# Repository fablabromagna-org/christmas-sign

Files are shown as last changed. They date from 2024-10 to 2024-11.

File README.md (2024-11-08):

# christmas-sign
Tre pomeriggi di open lab per realizzare insieme delle decorazioni a LED utilizzando CAD 2D-3D, Stampa 3D a colori, coding Arduino e Circuit Python.

# Circuito di controllo dei led
Il primo disegno KiCad prodotto è nella cartella ATtiny3.

La scelta di utilizzare un ATtiny è legata alla semplicità ed economicità di questa serie di microcontrollori.

L'idea era quella di creare un circuito che:
- potesse essere usato su una breadboard per i primi esperimenti
- fosse alimentabile con un cavo USB-C
- avesse a bordo un regolatore per 3.3v
- portasse fuori tutti i pin del'ATTiny
- avesse a bordo i driver di potenza per pilotare i led direttamente
- potesse essere programmato con un connettore UPDI standard a 6 pin (di cui solo 3 utilizzati)

Molti componenti sono SMD basic che non richiedono quindi una spesa aggiuntiva per il cambio reel sul Pick and place di JLCPCB.

Gli unici componenti extended sono:
- il connettore USB-C
- il regolatore di tensione 3.3v
- la CPU

La prima produzione di 10 schede per un totale di 434 componenti montati in SMD è costata 37 euro comprese VAT e shipping. (avevo un buono sconto di 8,26 euro)

A queste spese bisogna aggiungere le 10 CPU comprate su Mouser a 9,39 che andranno saldate a mano.

JLCPCB infatti non ha a catalogo queste CPU (ATtiny1624)

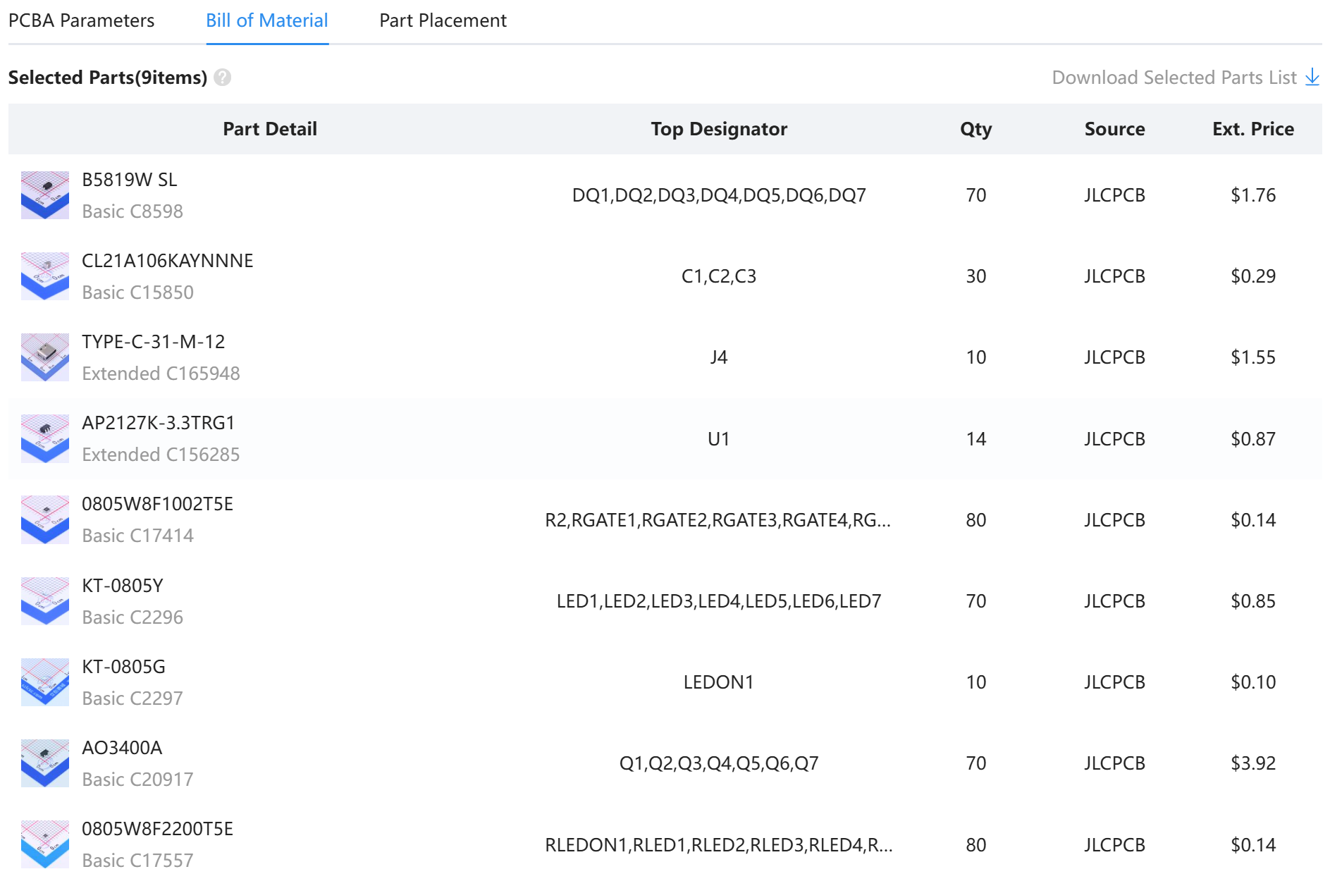
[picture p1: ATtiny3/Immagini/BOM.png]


Fronte
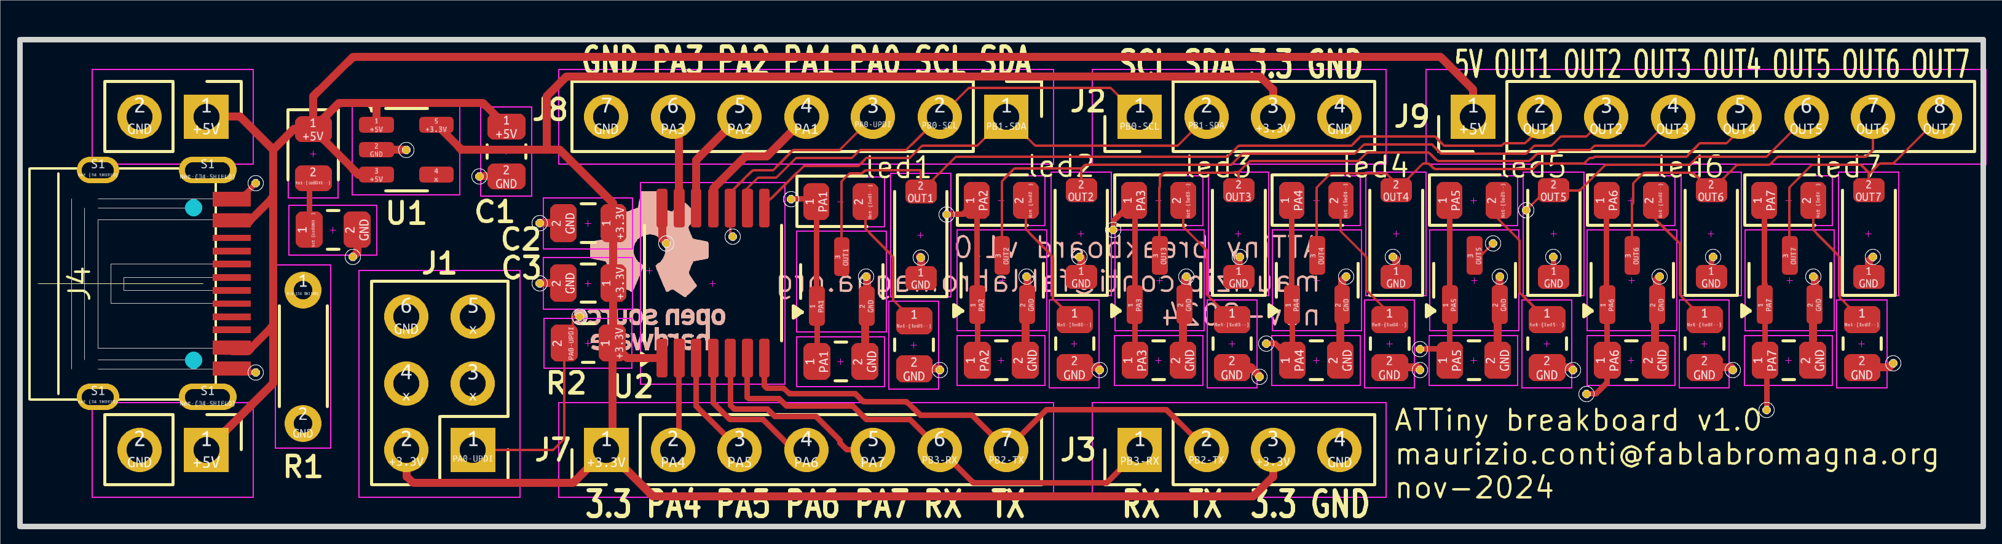
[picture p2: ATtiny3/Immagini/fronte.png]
Fronte


Retro
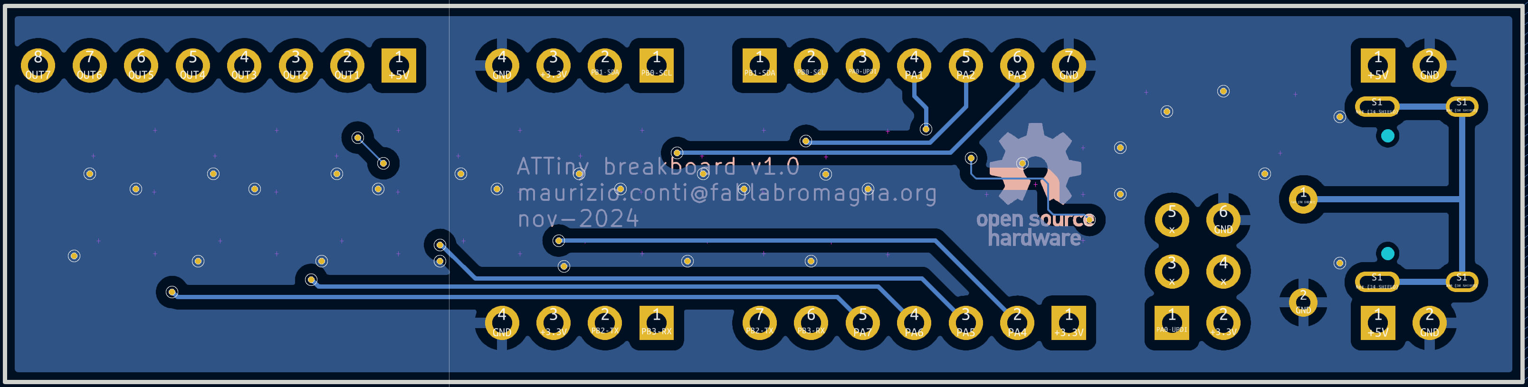
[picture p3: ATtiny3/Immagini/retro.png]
Retro


Schema
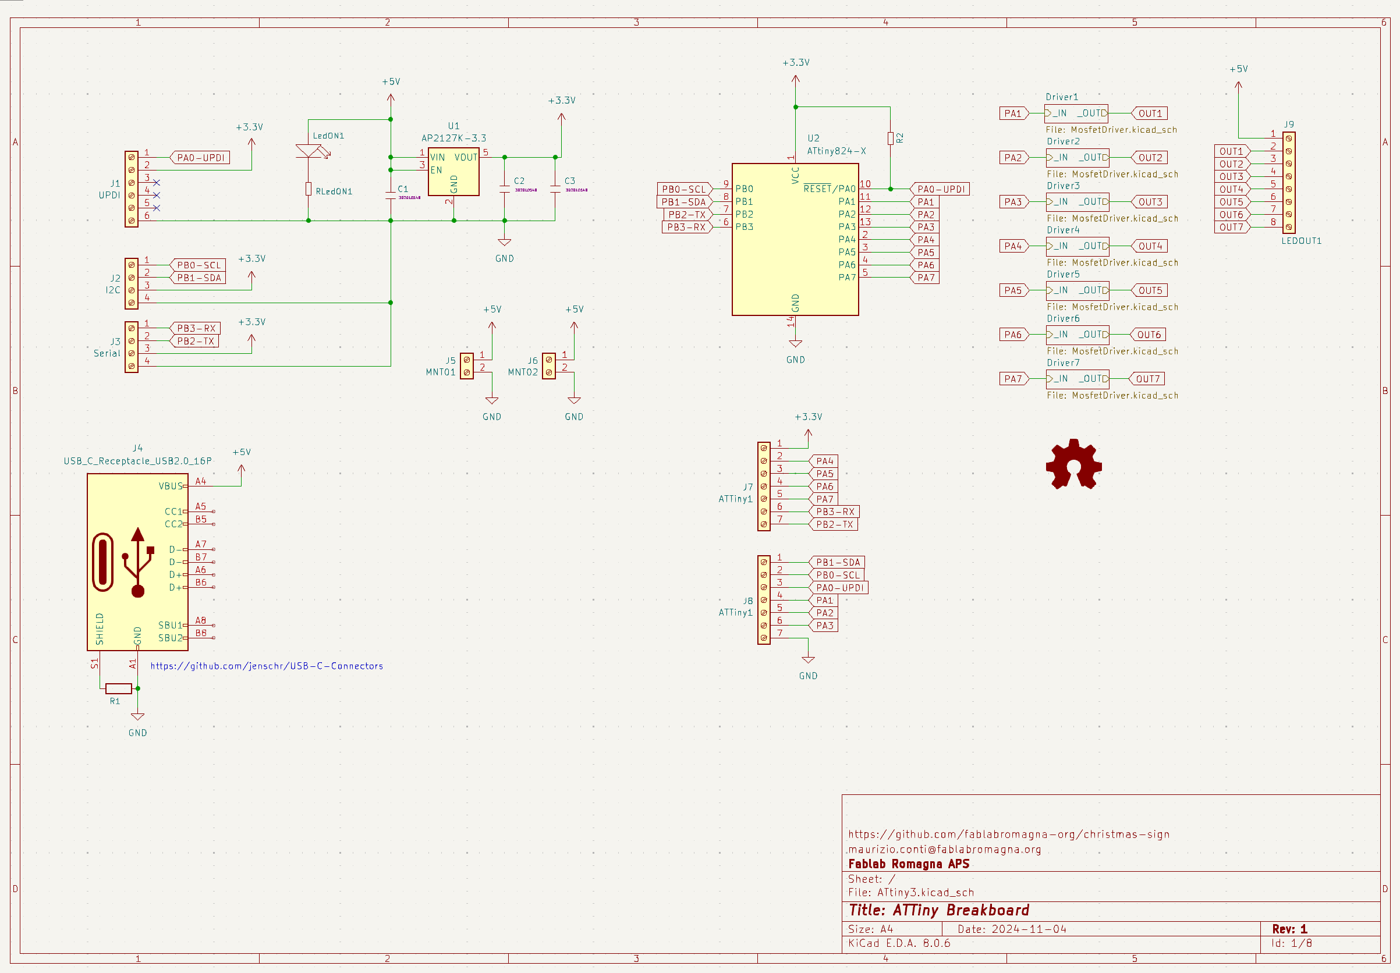
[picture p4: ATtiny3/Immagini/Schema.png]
Schema


Vista 3D
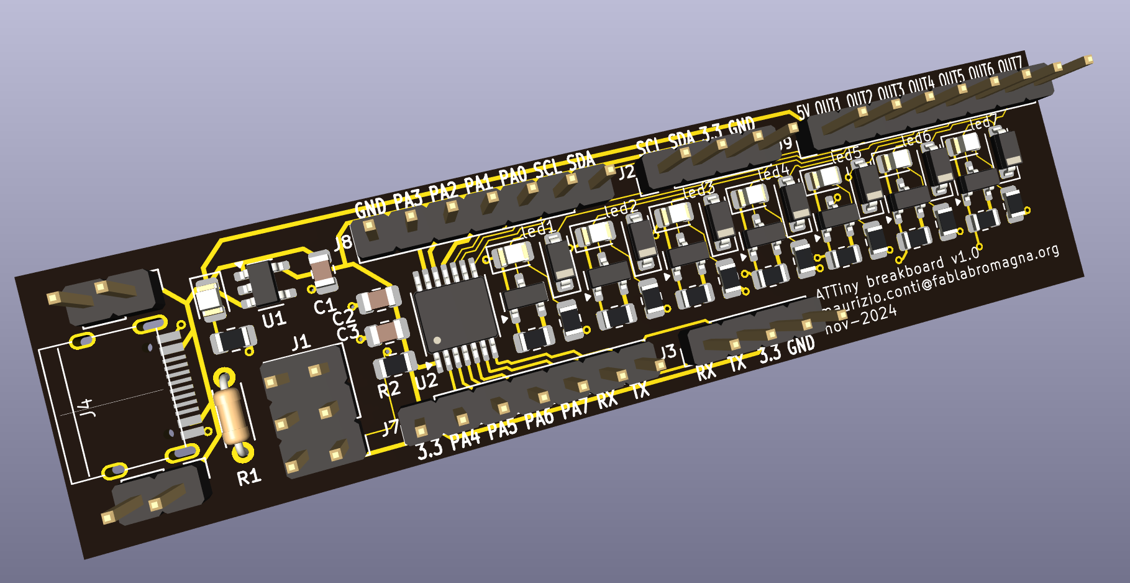
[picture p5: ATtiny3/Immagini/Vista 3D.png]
Vista 3D


Pdf dello schema **[PDF](ATtiny3/Immagini/Schema.pdf)**.

Così lo volevano loro...
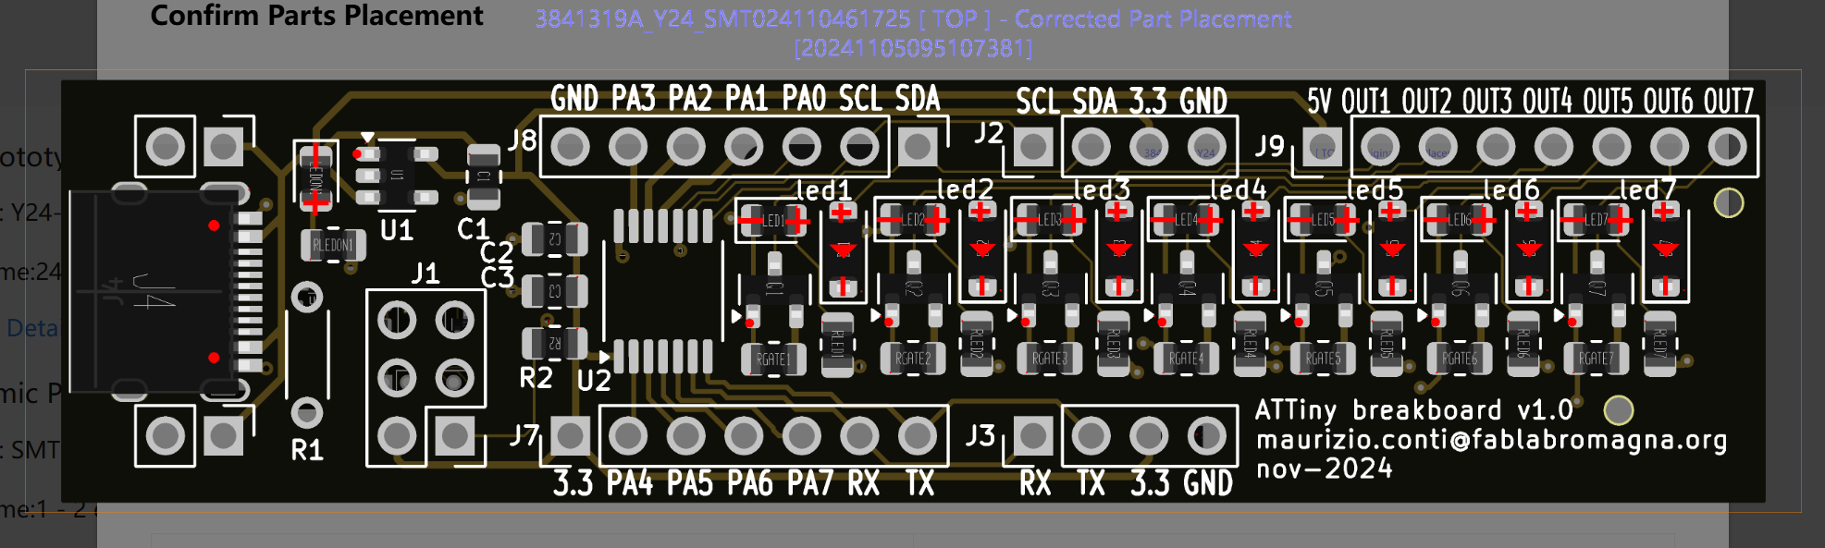
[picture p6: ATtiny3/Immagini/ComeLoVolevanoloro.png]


Così lo volevo io...
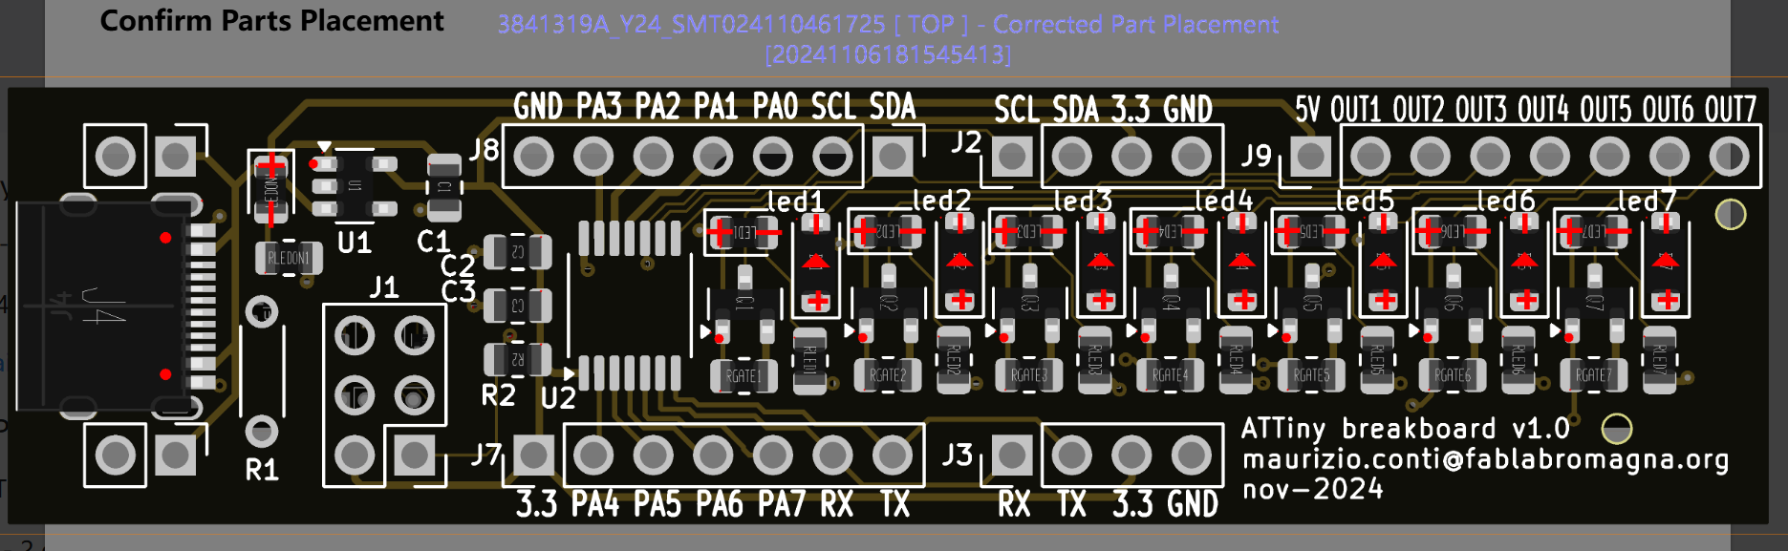
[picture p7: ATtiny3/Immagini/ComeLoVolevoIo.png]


Ci siamo messi d'accordo.
I diodi erano giusti ma a loro non piacevano.

Quando arriveranno i circuiti montati sapremo chi aveva ragione.

Nel frattempo però, un circuito confermato domenica 3 novembre 2024, va in produzione l'8 novembre, con 5 giorni di ritardo.

Loro chiedono scusa ma la prossima volta lo faccio con PCBWay e vediamo se il maggior costo è giustificato.

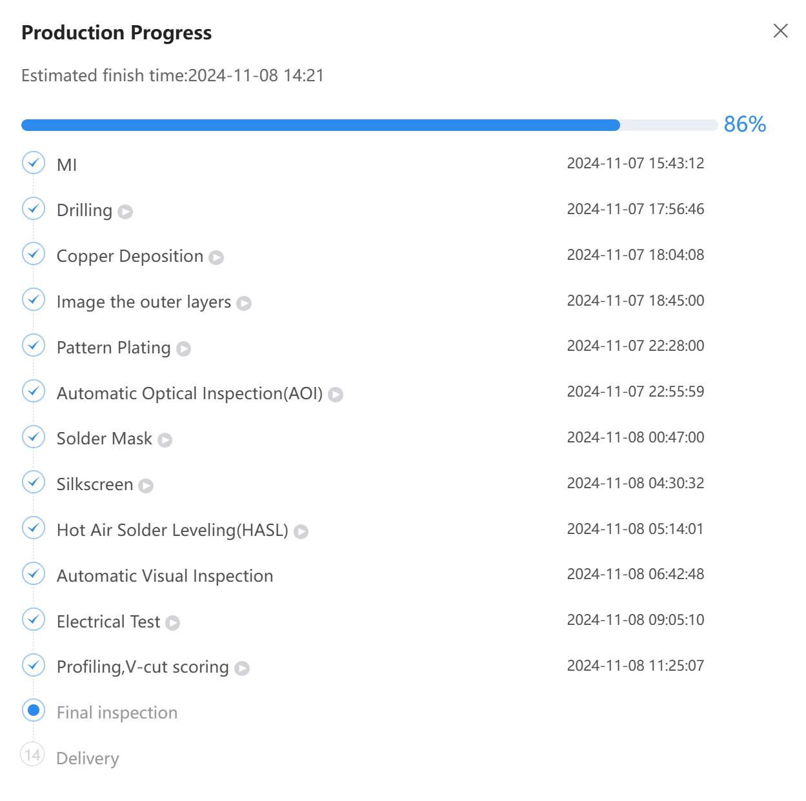
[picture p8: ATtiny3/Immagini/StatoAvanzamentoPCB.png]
Ci siamo


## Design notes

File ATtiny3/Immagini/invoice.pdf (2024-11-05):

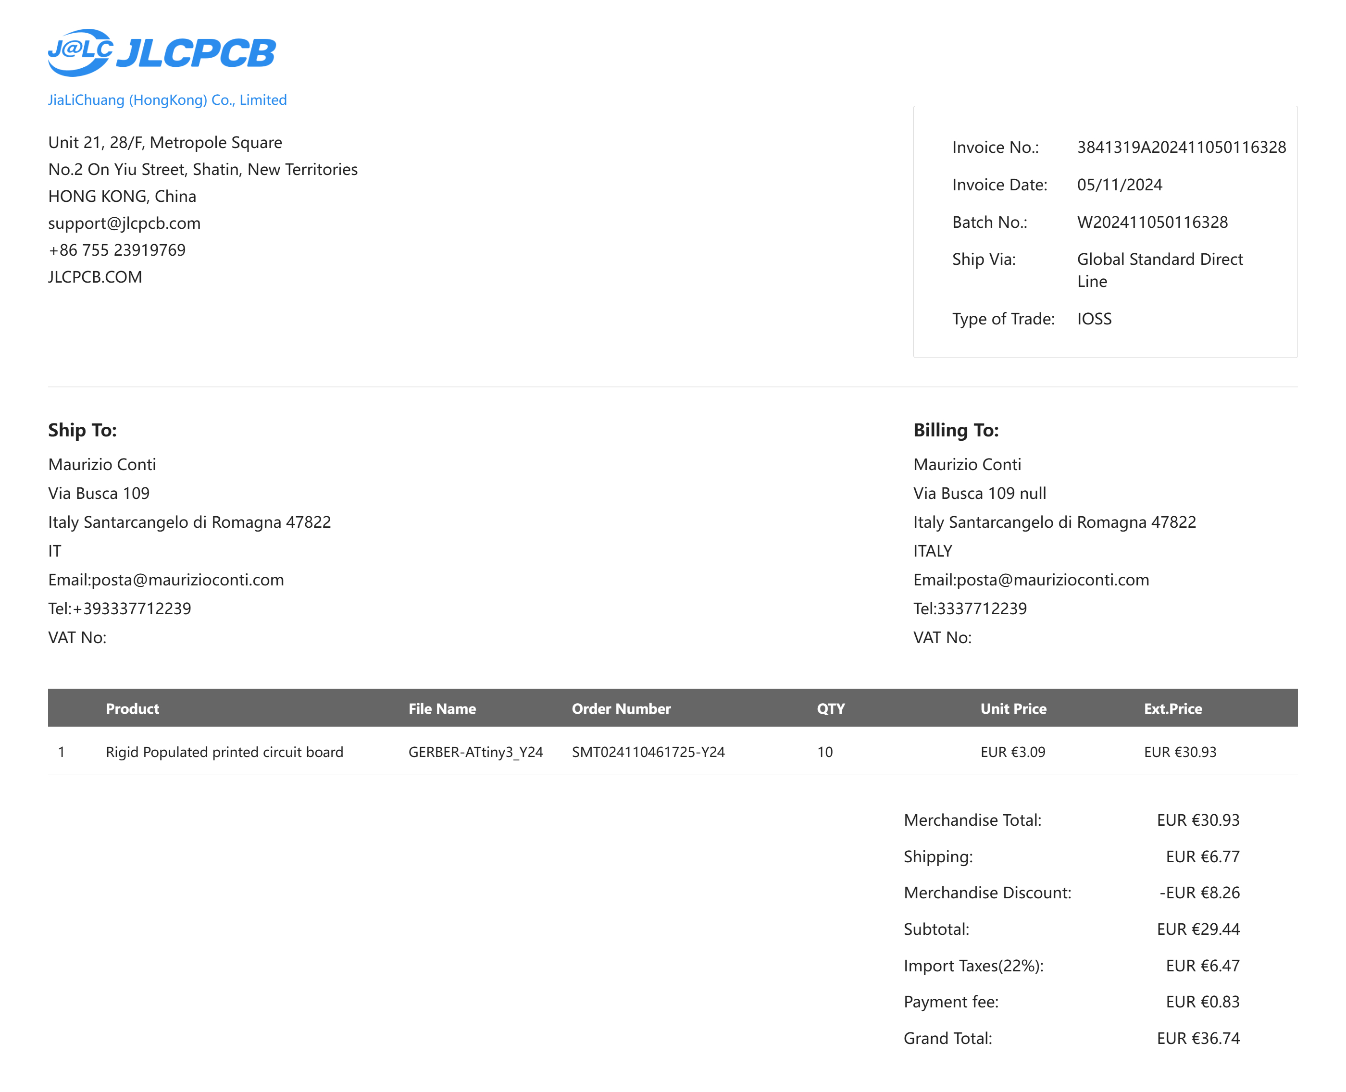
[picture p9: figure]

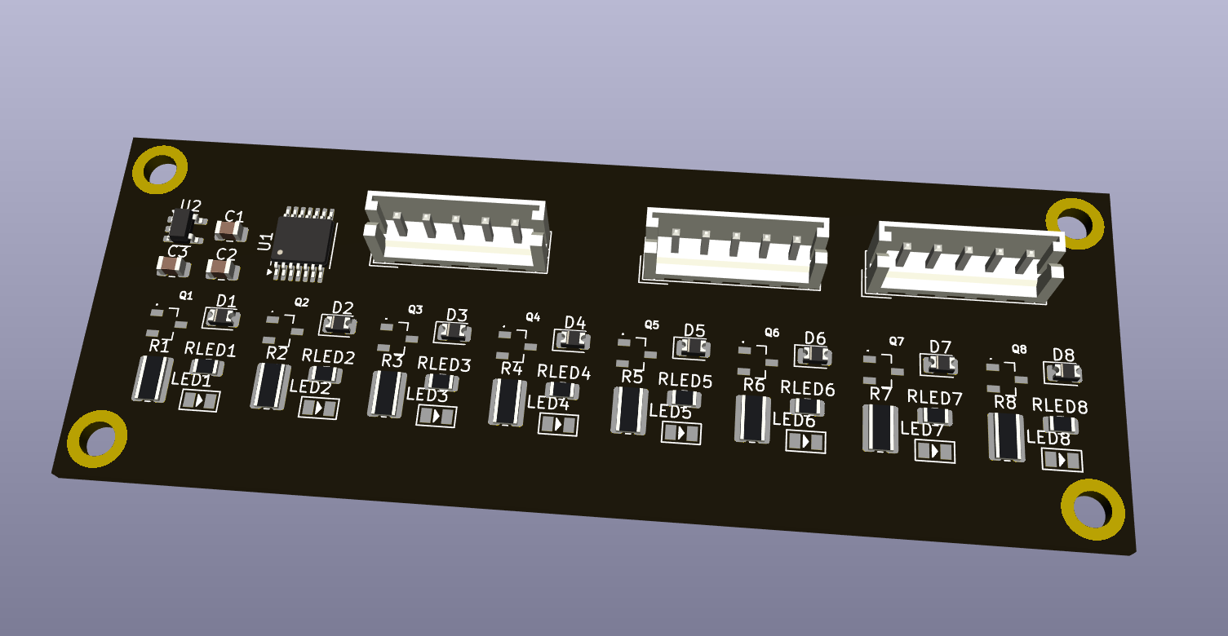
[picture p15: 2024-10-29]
ATtiny3/Immagini/primo layout.png

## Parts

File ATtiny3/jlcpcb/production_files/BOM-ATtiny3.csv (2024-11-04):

Comment | Designator | Footprint | LCSC
AP2127K-3.3 | U1 | SOT-23-5 | C156285
CERAMIC-10UF-10V-10%-X7R_0805_ | C1,C2,C3 | C_0805_2012Metric | C15850
USB_C_Receptacle_USB2.0_16P | J4 | TYPE-C-31-M-12 | C165948
10K | R2,rgate1,rgate2,rgate3,rgate4,rgate5,rgate6,rgate7 | R_0805_2012Metric | C17414
SMD-RES-220R-5%-1_8W_0805_ | RLedON1,rled1,rled2,rled3,rled4,rled5,rled6,rled7 | R_0805_2012Metric | C17557
SMD-MOSFET-N-CH | q1,q2,q3,q4,q5,q6,q7 | SOT-23 | C20917
SMD-LED-CLEAR-0805 | led1,led2,led3,led4,led5,led6,led7 | LED_0805_2012Metric | C2296
SMD-LED-CLEAR-RED_0805_ | LedON1 | LED_0805_2012Metric | C2297
SMD-DIODE-SCHOTTKY-20V-1A_SOD-123_ | dq1,dq2,dq3,dq4,dq5,dq6,dq7 | D_SOD-123 | C8598
Logo_Open_Hardware_Small | L1 | OSHW-Logo_5.7x6mm_SilkScreen

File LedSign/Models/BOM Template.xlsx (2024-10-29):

Designator | Manufacturer Part Number or Seeed SKU | Qty | Link
C1,C2,C3,C4,C5 | RHA0J471MCN1GS | 5 | https://www.digikey.com.cn/product-detail/zh/nichicon/RHA0J471MCN1GS/493-3771-1-ND/2209480
A1,A4 | RH0111-30002 | 2 | https://statics3.seeedstudio.com/images/opl/datasheet/318020010.pdf
D1 | CYBLE-014008-00 | 1 | https://www.digikey.com.cn/product-detail/zh/cypress-semiconductor-corp/CYBLE-014008-00/428-3600-1-ND/6052585

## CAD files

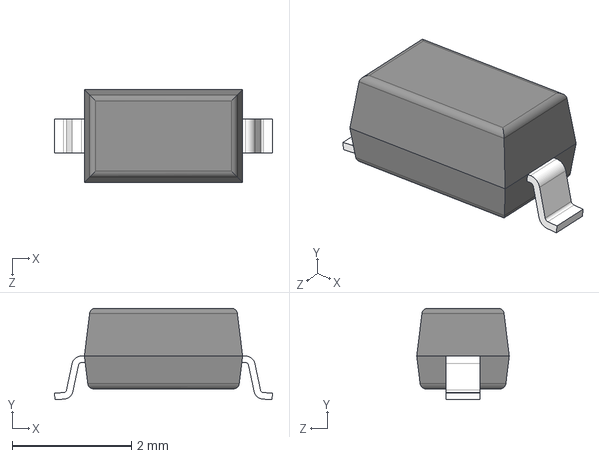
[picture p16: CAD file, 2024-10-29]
LedSign/Models/B5819W-TP.step
3.65 x 1.53 x 1.55 mm

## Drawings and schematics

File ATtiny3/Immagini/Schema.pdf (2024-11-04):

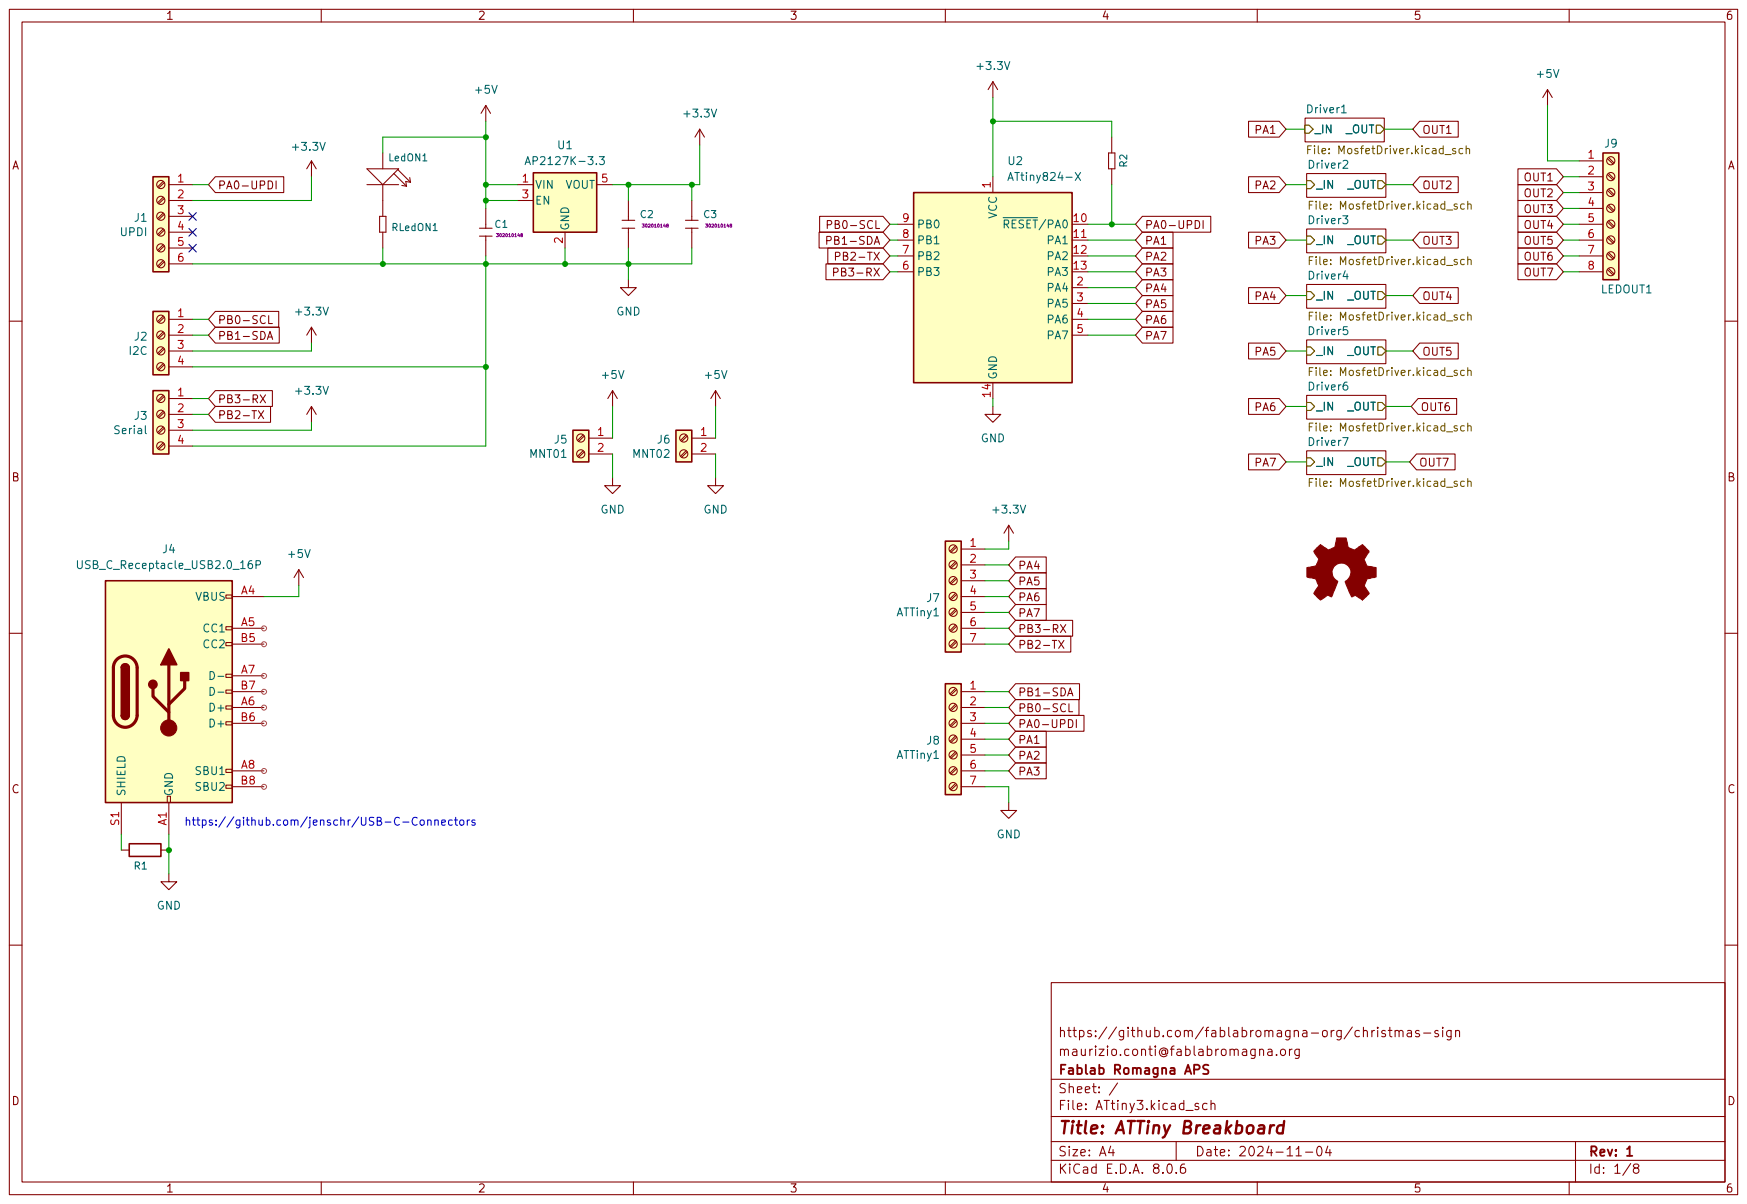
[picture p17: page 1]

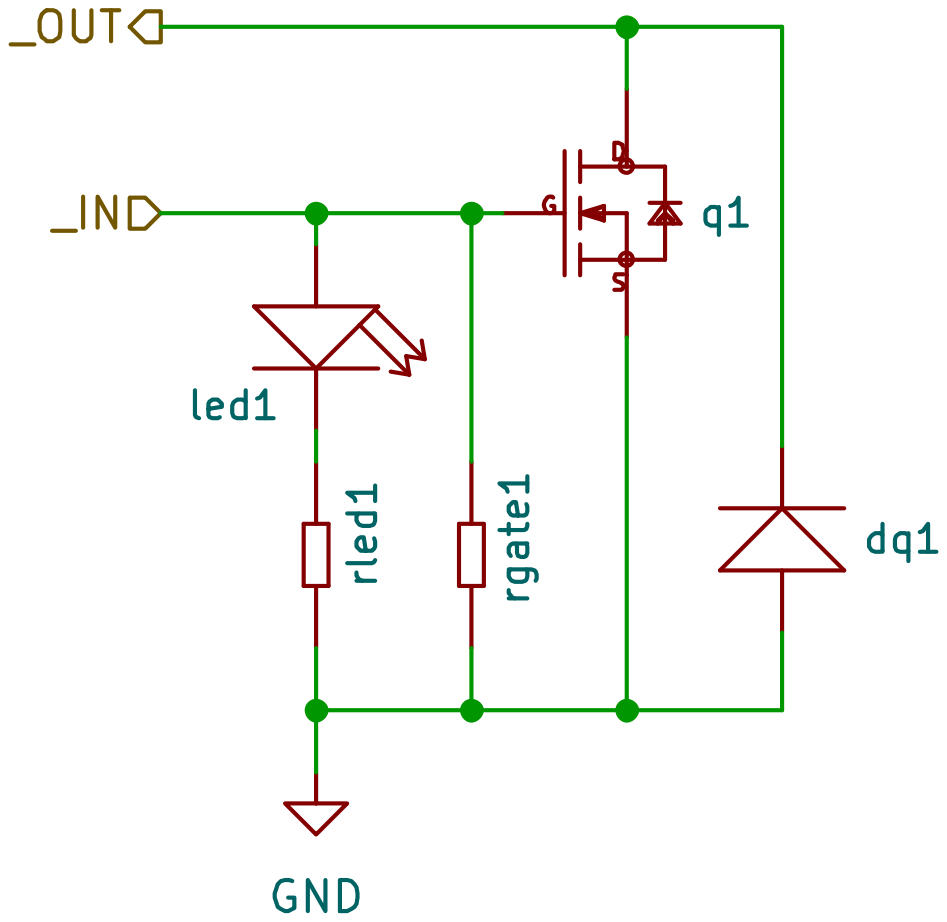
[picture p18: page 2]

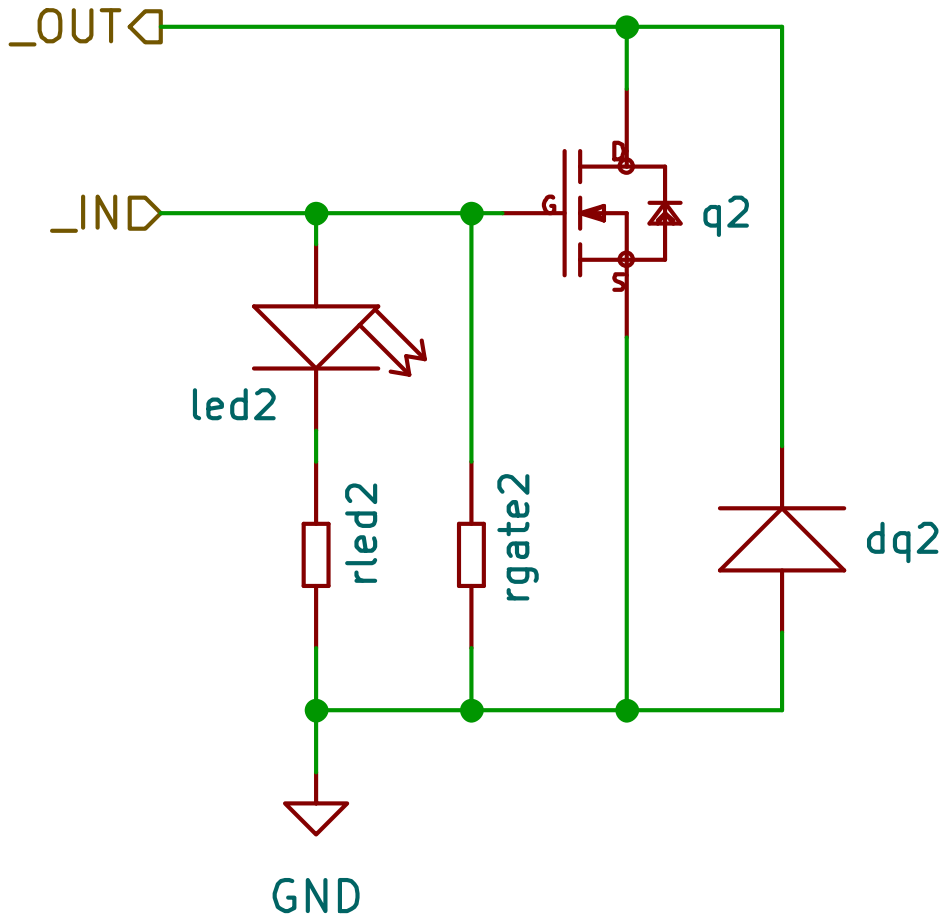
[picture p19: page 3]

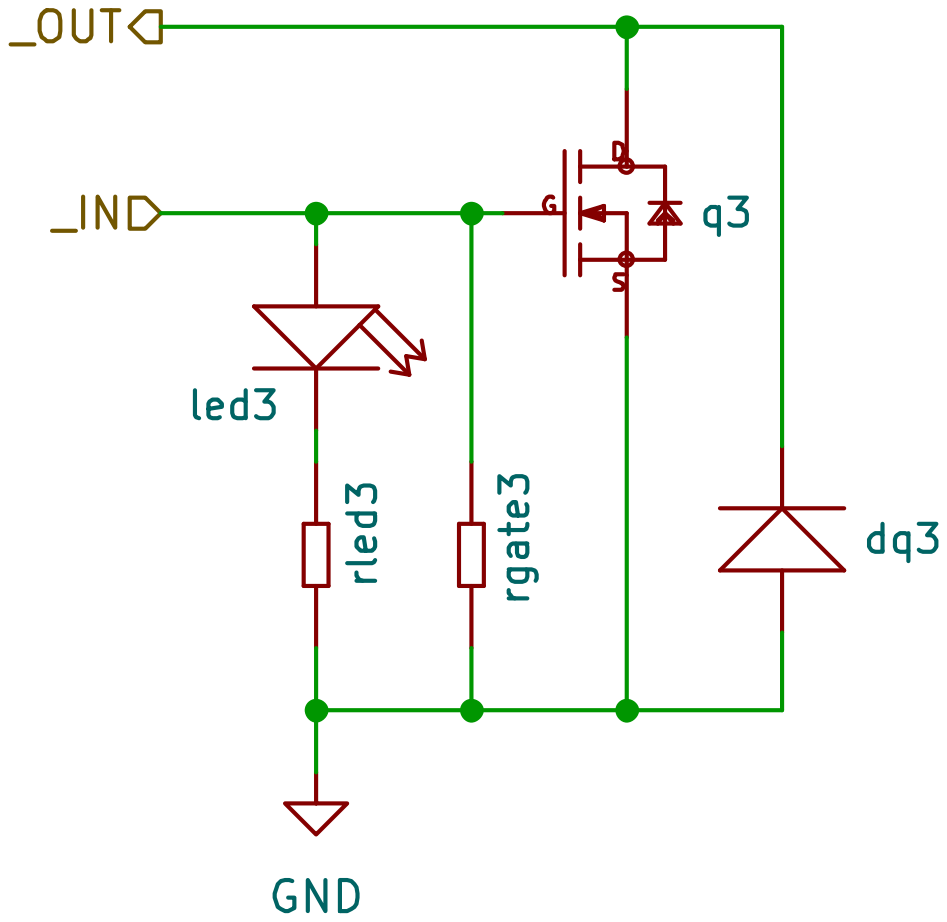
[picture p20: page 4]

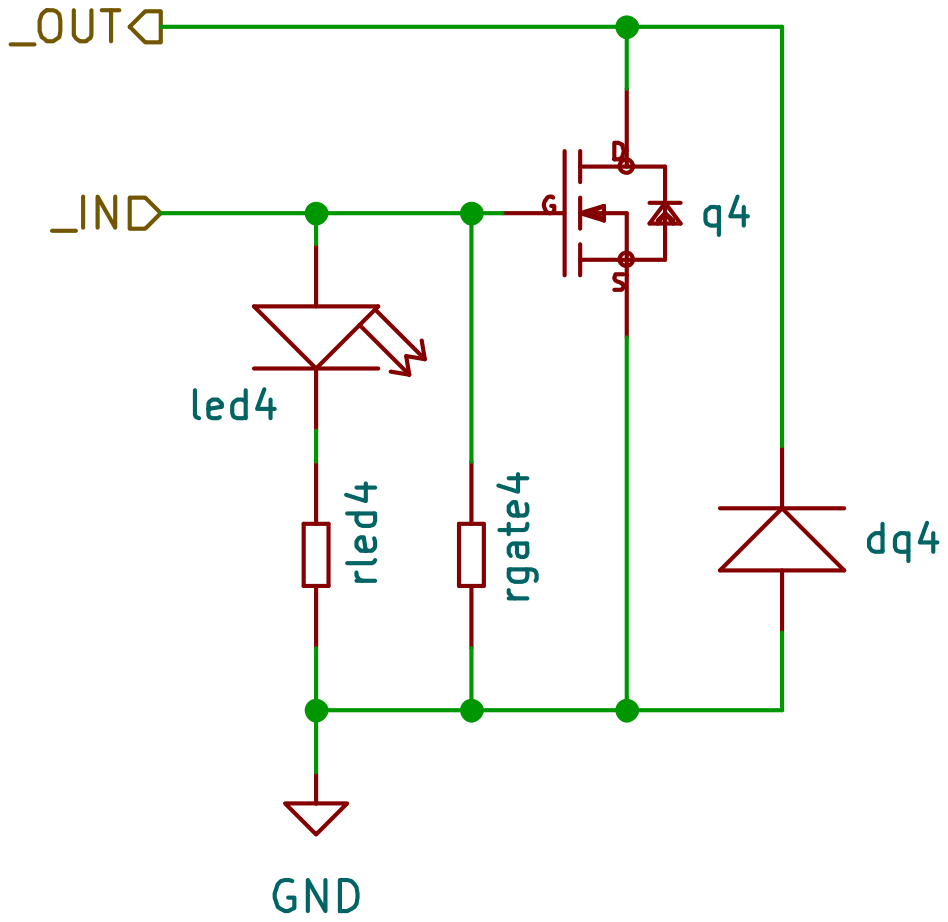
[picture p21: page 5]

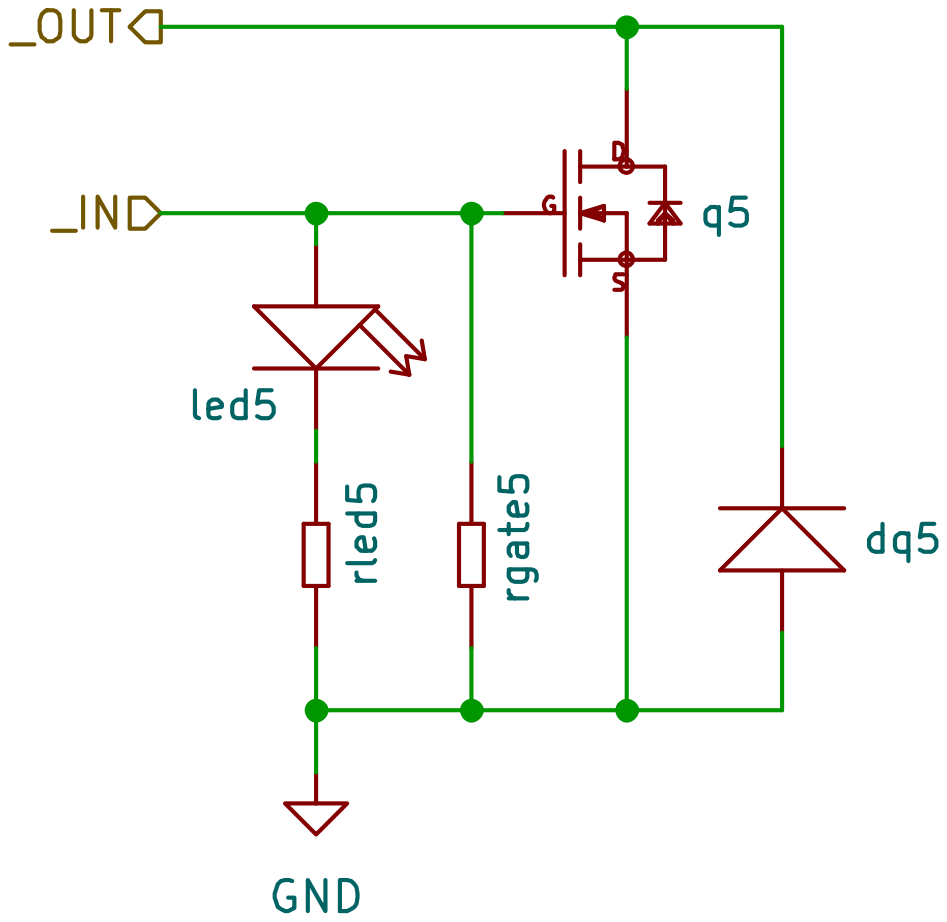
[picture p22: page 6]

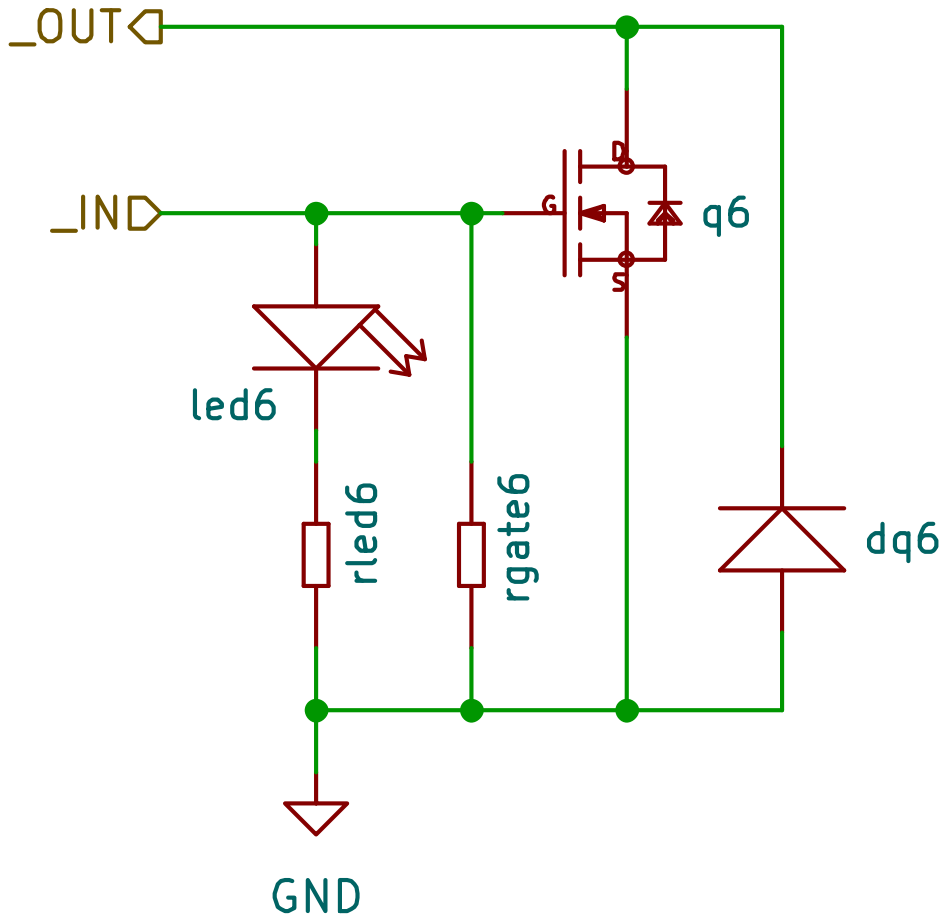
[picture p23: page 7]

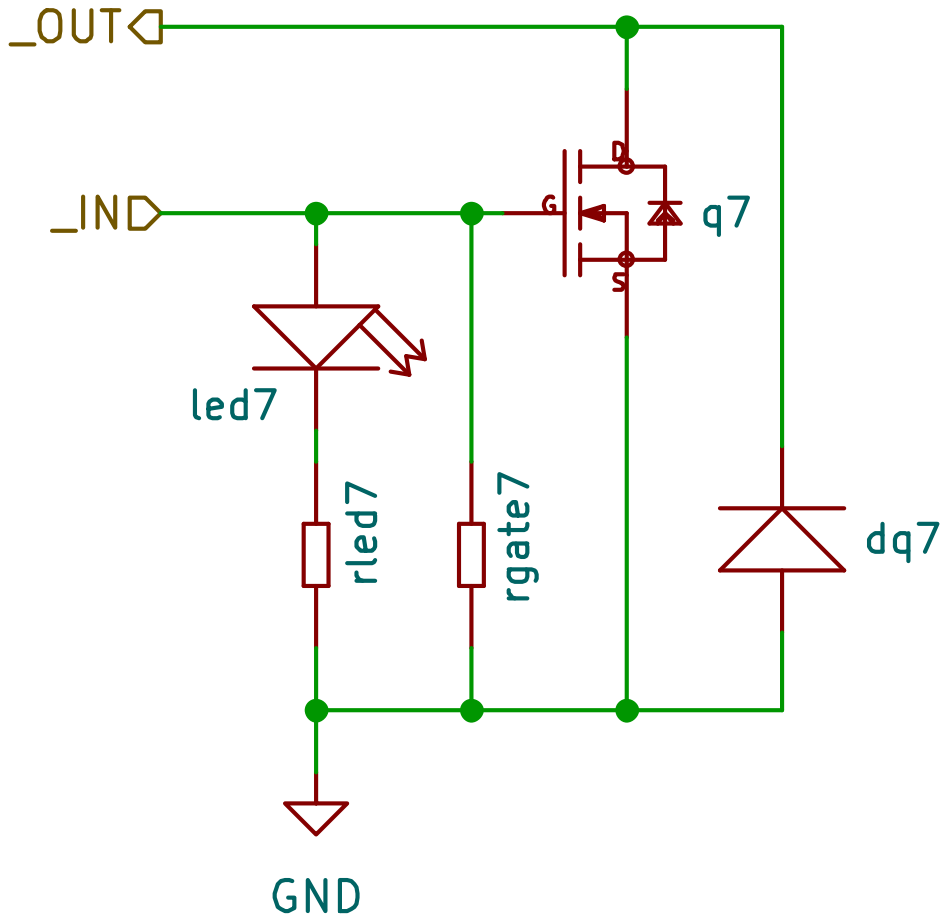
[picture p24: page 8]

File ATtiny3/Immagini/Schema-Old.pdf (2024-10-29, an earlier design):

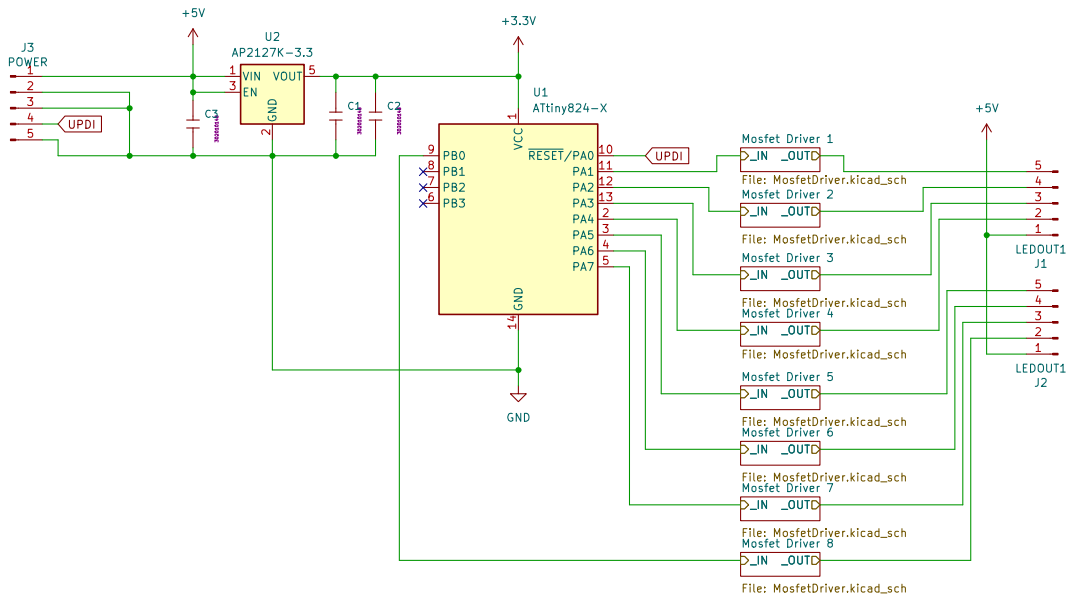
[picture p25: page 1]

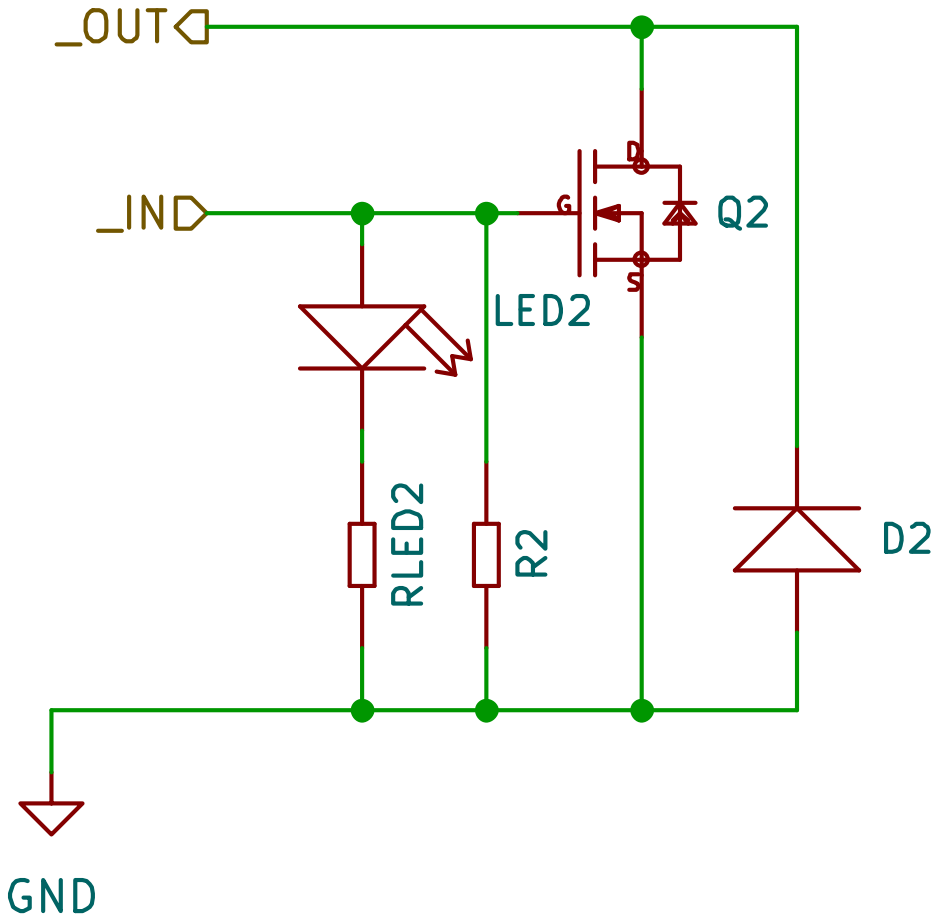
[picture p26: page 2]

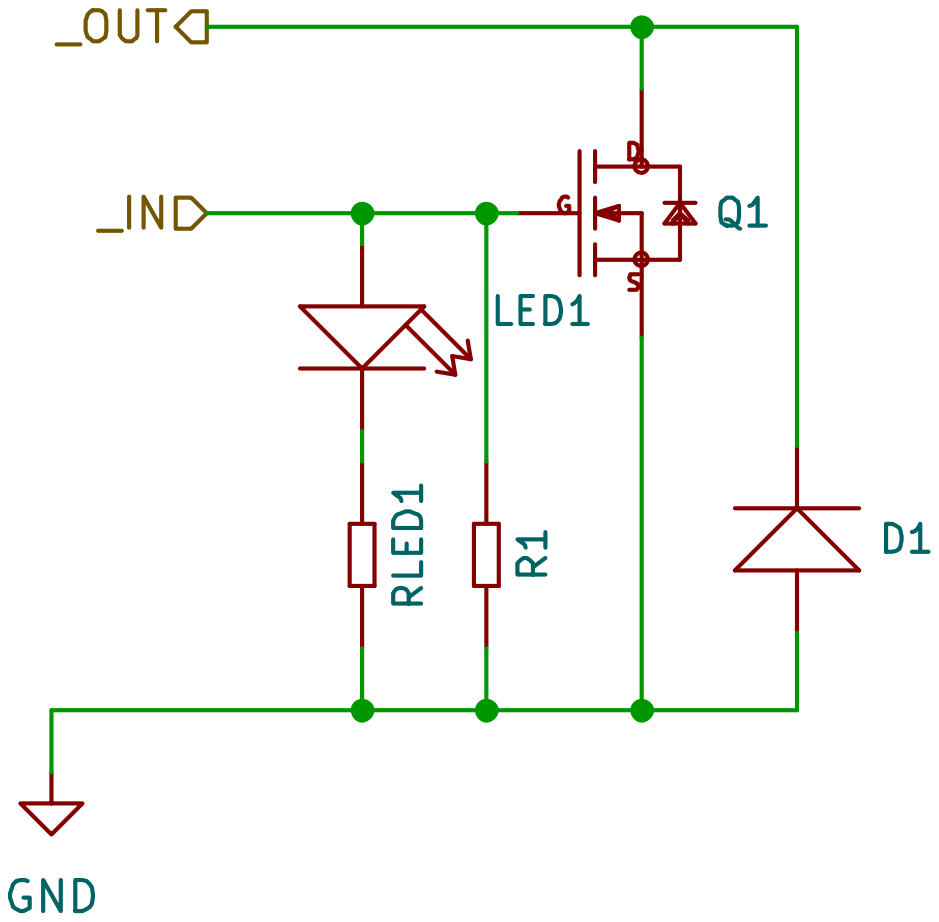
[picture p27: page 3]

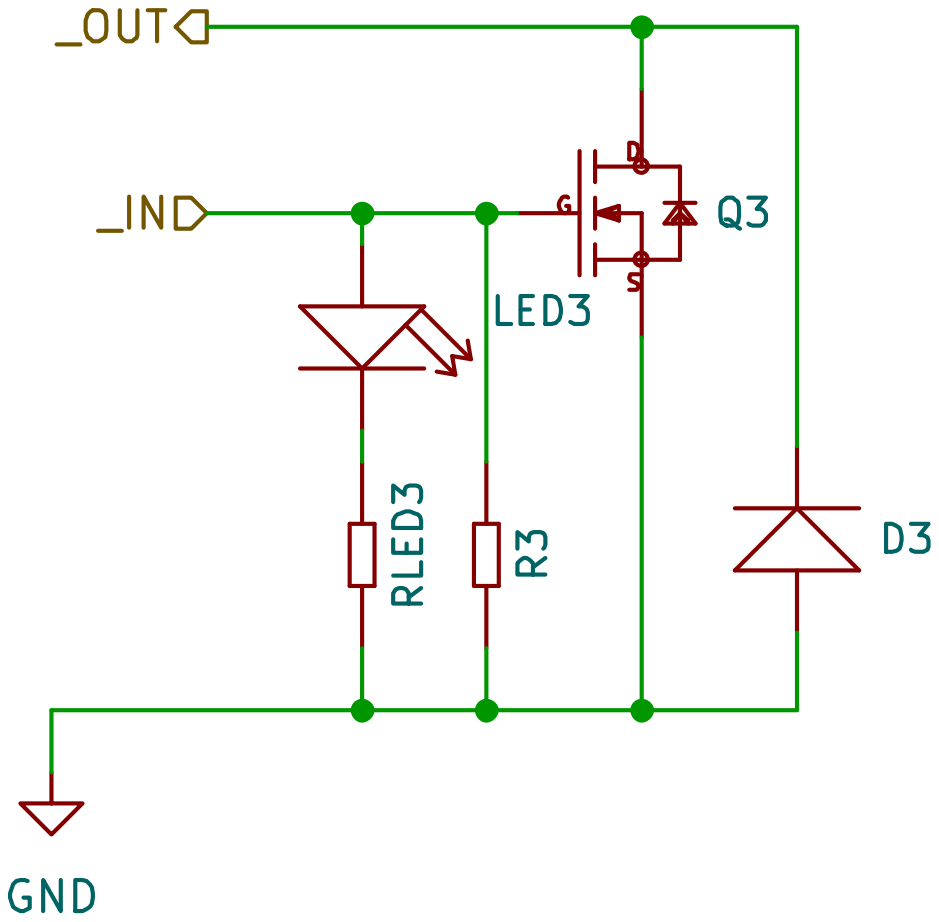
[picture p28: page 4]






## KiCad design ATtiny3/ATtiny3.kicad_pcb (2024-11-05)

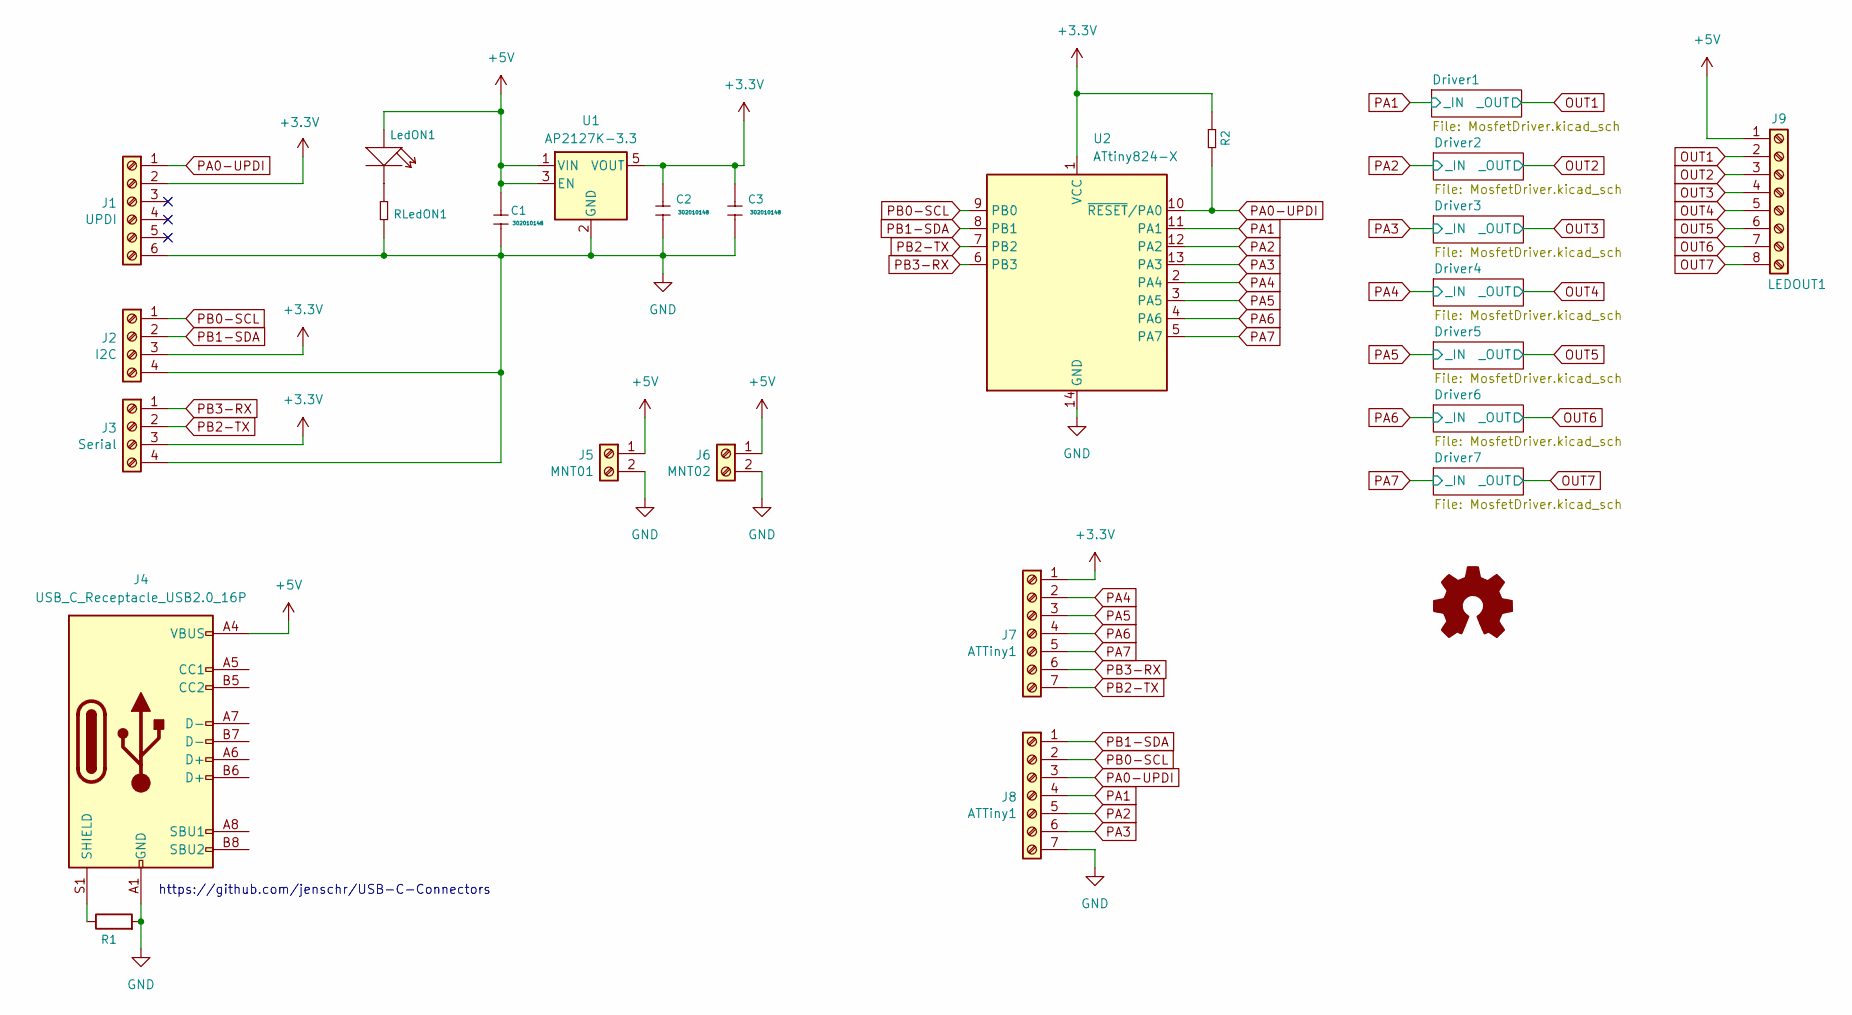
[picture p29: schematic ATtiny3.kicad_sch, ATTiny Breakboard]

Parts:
C1, C2, C3: CERAMIC-10UF-10V-10%-X7R_0805_; C_0805_2012Metric; MPN CC0805KKX7R8BB225; LCSC C15850
J1: UPDI; PinHeader_2x03_P2.54mm_Vertical
J2: I2C; PinHeader_1x04_P2.54mm_Vertical
J3: Serial; PinHeader_1x04_P2.54mm_Vertical
J4: USB_C_Receptacle_USB2.0_16P; TYPE-C-31-M-12; LCSC C165948
J5: MNT01; PinHeader_1x02_P2.54mm_Vertical
J6: MNT02; PinHeader_1x02_P2.54mm_Vertical
J7, J8: ATTiny1; PinHeader_1x07_P2.54mm_Vertical
J9: LEDOUT1; PinHeader_1x08_P2.54mm_Vertical
L1: Logo_Open_Hardware_Small; OSHW-Logo_5.7x6mm_SilkScreen
LedON1: SMD-LED-CLEAR-RED_0805_; LED_0805_2012Metric; MPN 17-215SURC_S530-A2_TR8; LCSC C2297
R1: 1M; R_Axial_DIN0204_L3.6mm_D1.6mm_P5.08mm_Horizontal
R2: 10K; R_0805_2012Metric; LCSC C17414
RLedON1: SMD-RES-220R-5%-1_8W_0805_; R_0805_2012Metric; LCSC C17557
U1: AP2127K-3.3; SOT-23-5; LCSC C156285
U2: ATtiny824-X; TSSOP-14_4.4x5mm_P0.65mm; LCSC C3237505

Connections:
+3.3V: C2.1, C3.1, J1.2, J2.3, J3.3, J7.1, R2.1, U1.5 (VOUT), U2.1 (VCC)
+5V: C1.1, J4.A4 (VBUS), J4.A9 (VBUS), J4.B4 (VBUS), J4.B9 (VBUS), J5.1, J6.1, J9.1, LedON1.1 (+), U1.1 (VIN), U1.3 (EN)
GND: C1.2, C2.2, C3.2, J1.6, J2.4, J3.4, J4.A1 (GND), J4.A12 (GND), J4.B1 (GND), J4.B12 (GND), J5.2, J6.2, J8.7, R1.2, RLedON1.2, U1.2 (GND), U2.14 (GND); also elsewhere on the board
unnamed: J4.S1 (SHIELD), R1.1
unnamed: LedON1.2 (-), RLedON1.1
OUT1: J9.2; also elsewhere on the board
OUT2: J9.3; also elsewhere on the board
OUT3: J9.4; also elsewhere on the board
OUT4: J9.5; also elsewhere on the board
OUT5: J9.6; also elsewhere on the board
OUT6: J9.7; also elsewhere on the board
OUT7: J9.8; also elsewhere on the board
PA0-UPDI: J1.1, J8.3, R2.2, U2.10 (~RESET/PA0)
PA1: J8.4, U2.11 (PA1); also elsewhere on the board
PA2: J8.5, U2.12 (PA2); also elsewhere on the board
PA3: J8.6, U2.13 (PA3); also elsewhere on the board
PA4: J7.2, U2.2 (PA4); also elsewhere on the board
PA5: J7.3, U2.3 (PA5); also elsewhere on the board
PA6: J7.4, U2.4 (PA6); also elsewhere on the board
PA7: J7.5, U2.5 (PA7); also elsewhere on the board
PB0-SCL: J2.1, J8.2, U2.9 (PB0)
PB1-SDA: J2.2, J8.1, U2.8 (PB1)
PB2-TX: J3.2, J7.7, U2.7 (PB2)
PB3-RX: J3.1, J7.6, U2.6 (PB3)

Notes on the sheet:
https://github.com/jenschr/USB-C-Connectors

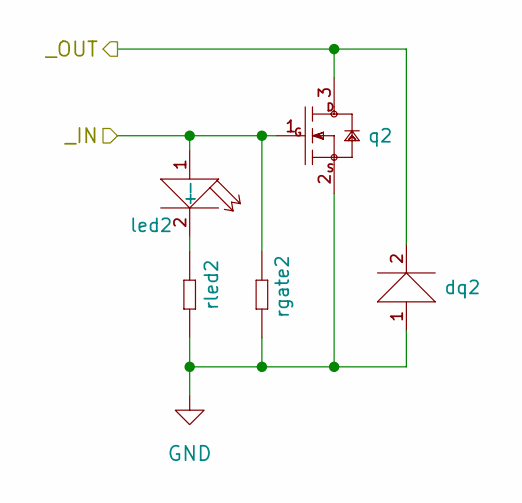
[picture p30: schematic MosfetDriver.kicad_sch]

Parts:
dq2: SMD-DIODE-SCHOTTKY-20V-1A_SOD-123_; D_SOD-123; LCSC C8598
led2: SMD-LED-CLEAR-0805; LED_0805_2012Metric; LCSC C2296
q2: SMD-MOSFET-N-CH; SOT-23; LCSC C20917
rgate2: 10K; R_0805_2012Metric; MPN RC0805JR-074K7L; LCSC C17414
rled2: SMD-RES-220R-5%-1_8W_0805_; R_0805_2012Metric; MPN RC0805JR-07220RL; LCSC C17557

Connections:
GND: dq2.1 (+), q2.2 (S), rgate2.2, rled2.2; also elsewhere on the board
unnamed: led2.2 (-), rled2.1
OUT2: dq2.2 (-), q2.3 (D); also elsewhere on the board
PA2: led2.1 (+), q2.1 (G), rgate2.1; also elsewhere on the board

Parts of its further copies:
dq1, dq3, dq4, dq5, dq6, dq7: SMD-DIODE-SCHOTTKY-20V-1A_SOD-123_; D_SOD-123; LCSC C8598
led1, led3, led4, led5, led6, led7: SMD-LED-CLEAR-0805; LED_0805_2012Metric; LCSC C2296
q1, q3, q4, q5, q6, q7: SMD-MOSFET-N-CH; SOT-23; LCSC C20917
rgate1, rgate3, rgate4, rgate5, rgate6, rgate7: 10K; R_0805_2012Metric; MPN RC0805JR-074K7L; LCSC C17414
rled1, rled3, rled4, rled5, rled6, rled7: SMD-RES-220R-5%-1_8W_0805_; R_0805_2012Metric; MPN RC0805JR-07220RL; LCSC C17557

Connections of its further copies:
GND: dq1.1 (+), dq3.1 (+), dq4.1 (+), dq5.1 (+), dq6.1 (+), dq7.1 (+), q1.2 (S), q3.2 (S), q4.2 (S), q5.2 (S), q6.2 (S), q7.2 (S), rgate1.2, rgate3.2, rgate4.2, rgate5.2, rgate6.2, rgate7.2, rled1.2, rled3.2, rled4.2, rled5.2, rled6.2, rled7.2; also elsewhere on the board
unnamed: led1.2 (-), rled1.1
unnamed: led3.2 (-), rled3.1
unnamed: led4.2 (-), rled4.1
unnamed: led5.2 (-), rled5.1
unnamed: led6.2 (-), rled6.1
unnamed: led7.2 (-), rled7.1
OUT1: dq1.2 (-), q1.3 (D); also elsewhere on the board
OUT3: dq3.2 (-), q3.3 (D); also elsewhere on the board
OUT4: dq4.2 (-), q4.3 (D); also elsewhere on the board
OUT5: dq5.2 (-), q5.3 (D); also elsewhere on the board
OUT6: dq6.2 (-), q6.3 (D); also elsewhere on the board
OUT7: dq7.2 (-), q7.3 (D); also elsewhere on the board
PA1: led1.1 (+), q1.1 (G), rgate1.1; also elsewhere on the board
PA3: led3.1 (+), q3.1 (G), rgate3.1; also elsewhere on the board
PA4: led4.1 (+), q4.1 (G), rgate4.1; also elsewhere on the board
PA5: led5.1 (+), q5.1 (G), rgate5.1; also elsewhere on the board
PA6: led6.1 (+), q6.1 (G), rgate6.1; also elsewhere on the board
PA7: led7.1 (+), q7.1 (G), rgate7.1; also elsewhere on the board

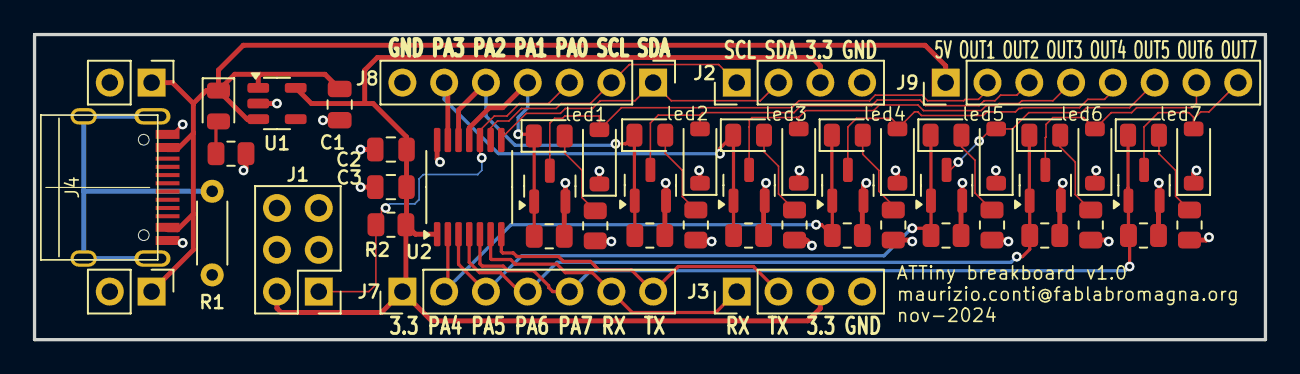
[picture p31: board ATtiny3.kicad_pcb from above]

Board: 2 copper layers, 74.8 x 18.5 mm, 54 parts (1 on the bottom side), 31 nets.

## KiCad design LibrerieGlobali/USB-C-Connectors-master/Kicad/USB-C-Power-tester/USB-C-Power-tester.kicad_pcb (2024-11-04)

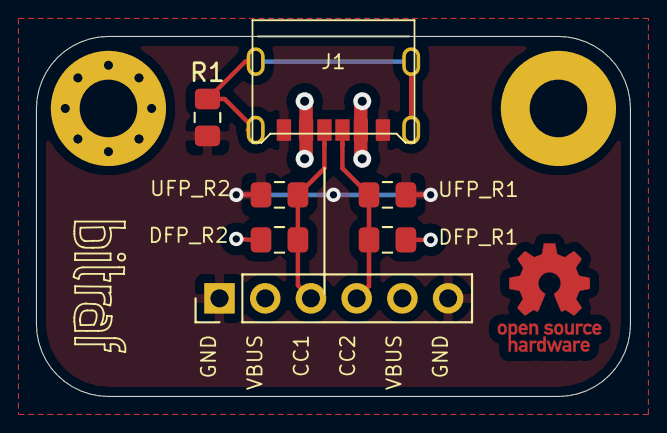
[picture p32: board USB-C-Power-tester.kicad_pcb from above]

Board: 2 copper layers, 33.0 x 20.0 mm, 11 parts (0 on the bottom side), 5 nets.

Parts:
DFP_R1, DFP_R2: DFP; R_0805_2012Metric_Pad1.15x1.40mm_HandSolder
H1: MountingHole; MountingHole_3.2mm_M3_Pad_Via
H3: MountingHole; MountingHole_3.2mm_M3_Pad
J1: USB_C_Receptacle_USB2.0; TYPE-C-31-M-17
L1: Logo_Open_Hardware_Small; OSHW-Logo_5.7x6mm_Copper
L2: Logo_Open_Hardware_Small; Bitraf_logo_3.0_x_7.5_mm
PIN1: Screw_Terminal_01x06; PinHeader_1x06_P2.54mm_Vertical
R1: 1M; R_0805_2012Metric_Pad1.15x1.40mm_HandSolder
UFP_R1, UFP_R2: UFP; R_0805_2012Metric_Pad1.15x1.40mm_HandSolder

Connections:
GND: J1.A12, J1.B12, PIN1.1, PIN1.6, R1.1, UFP_R1.2, UFP_R2.2
unnamed: DFP_R1.1, J1.A5, PIN1.4, UFP_R1.1
unnamed: DFP_R2.1, J1.B5, PIN1.3, UFP_R2.1
unnamed: J1.S1, R1.2
VBUS: DFP_R1.2, DFP_R2.2, J1.A9, J1.B9, PIN1.2, PIN1.5

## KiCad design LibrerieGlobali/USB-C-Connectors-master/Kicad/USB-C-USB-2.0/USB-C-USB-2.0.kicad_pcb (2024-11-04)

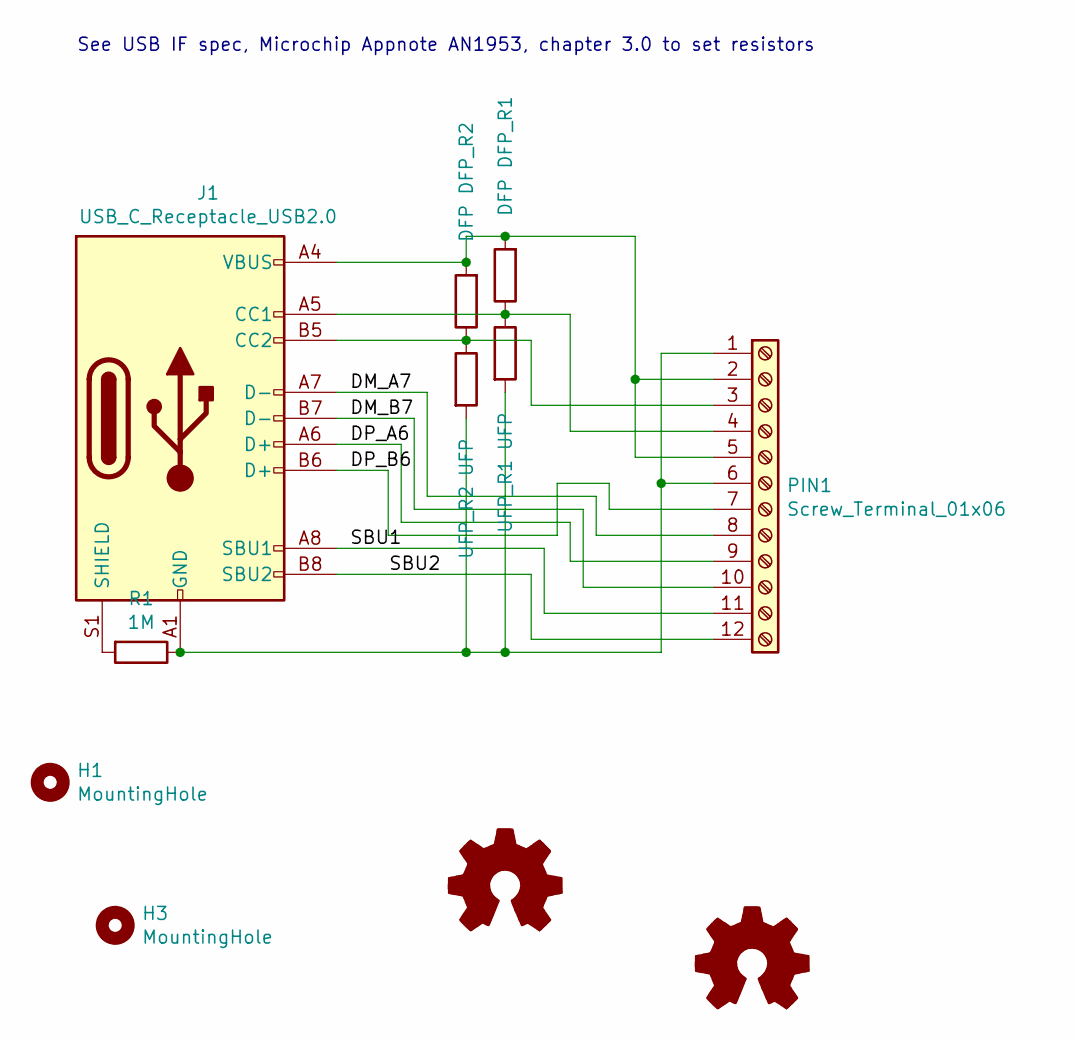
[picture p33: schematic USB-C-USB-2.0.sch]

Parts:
DFP_R1, DFP_R2: DFP; R_0805_2012Metric_Pad1.15x1.40mm_HandSolder
H1: MountingHole; MountingHole_3.2mm_M3_Pad_Via
H3: MountingHole; MountingHole_3.2mm_M3_Pad
J1: USB_C_Receptacle_USB2.0; TYPE-C-31-M-12; MPN TYPE-C-31-M-17
L1: Logo_Open_Hardware_Small; OSHW-Logo_5.7x6mm_SilkScreen
L2: Logo_Open_Hardware_Small; Bitraf_logo_3.0_x_7.5_mm
PIN1: Screw_Terminal_01x06; PinHeader_1x12_P2.54mm_Vertical
R1: 1M; R_0805_2012Metric_Pad1.15x1.40mm_HandSolder
UFP_R1, UFP_R2: UFP; R_0805_2012Metric_Pad1.15x1.40mm_HandSolder

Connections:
/DM_A7: J1.A7 (D-), PIN1.8
/DM_B7: J1.B7 (D-), PIN1.10
/DP_A6: J1.A6 (D+), PIN1.9
/DP_B6: J1.B6 (D+), PIN1.7
/SBU1: J1.A8 (SBU1), PIN1.11
/SBU2: J1.B8 (SBU2), PIN1.12
GND: J1.A1 (GND), J1.A12 (GND), J1.B1 (GND), J1.B12 (GND), PIN1.1, PIN1.6, R1.1, UFP_R1.2, UFP_R2.2
unnamed: DFP_R1.1, J1.A5 (CC1), PIN1.4, UFP_R1.1
unnamed: DFP_R2.1, J1.B5 (CC2), PIN1.3, UFP_R2.1
unnamed: J1.S1 (SHIELD), R1.2
VBUS: DFP_R1.2, DFP_R2.2, J1.A4 (VBUS), J1.A9 (VBUS), J1.B4 (VBUS), J1.B9 (VBUS), PIN1.2, PIN1.5

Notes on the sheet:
See USB IF spec, Microchip Appnote AN1953, chapter 3.0 to set resistors

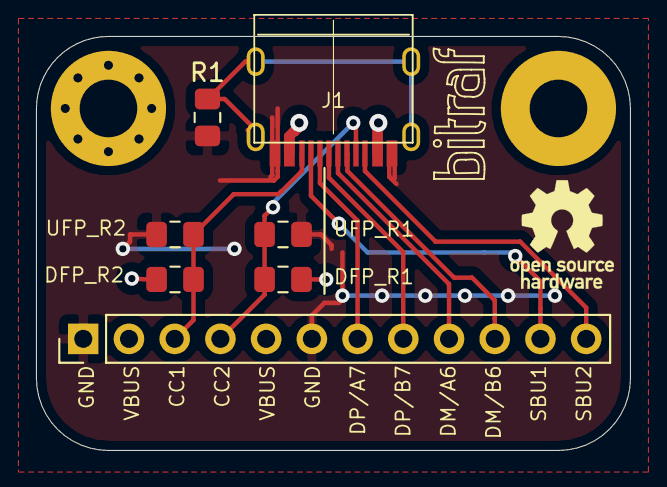
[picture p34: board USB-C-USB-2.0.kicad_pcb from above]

Board: 2 copper layers, 33.0 x 23.0 mm, 11 parts (0 on the bottom side), 11 nets.

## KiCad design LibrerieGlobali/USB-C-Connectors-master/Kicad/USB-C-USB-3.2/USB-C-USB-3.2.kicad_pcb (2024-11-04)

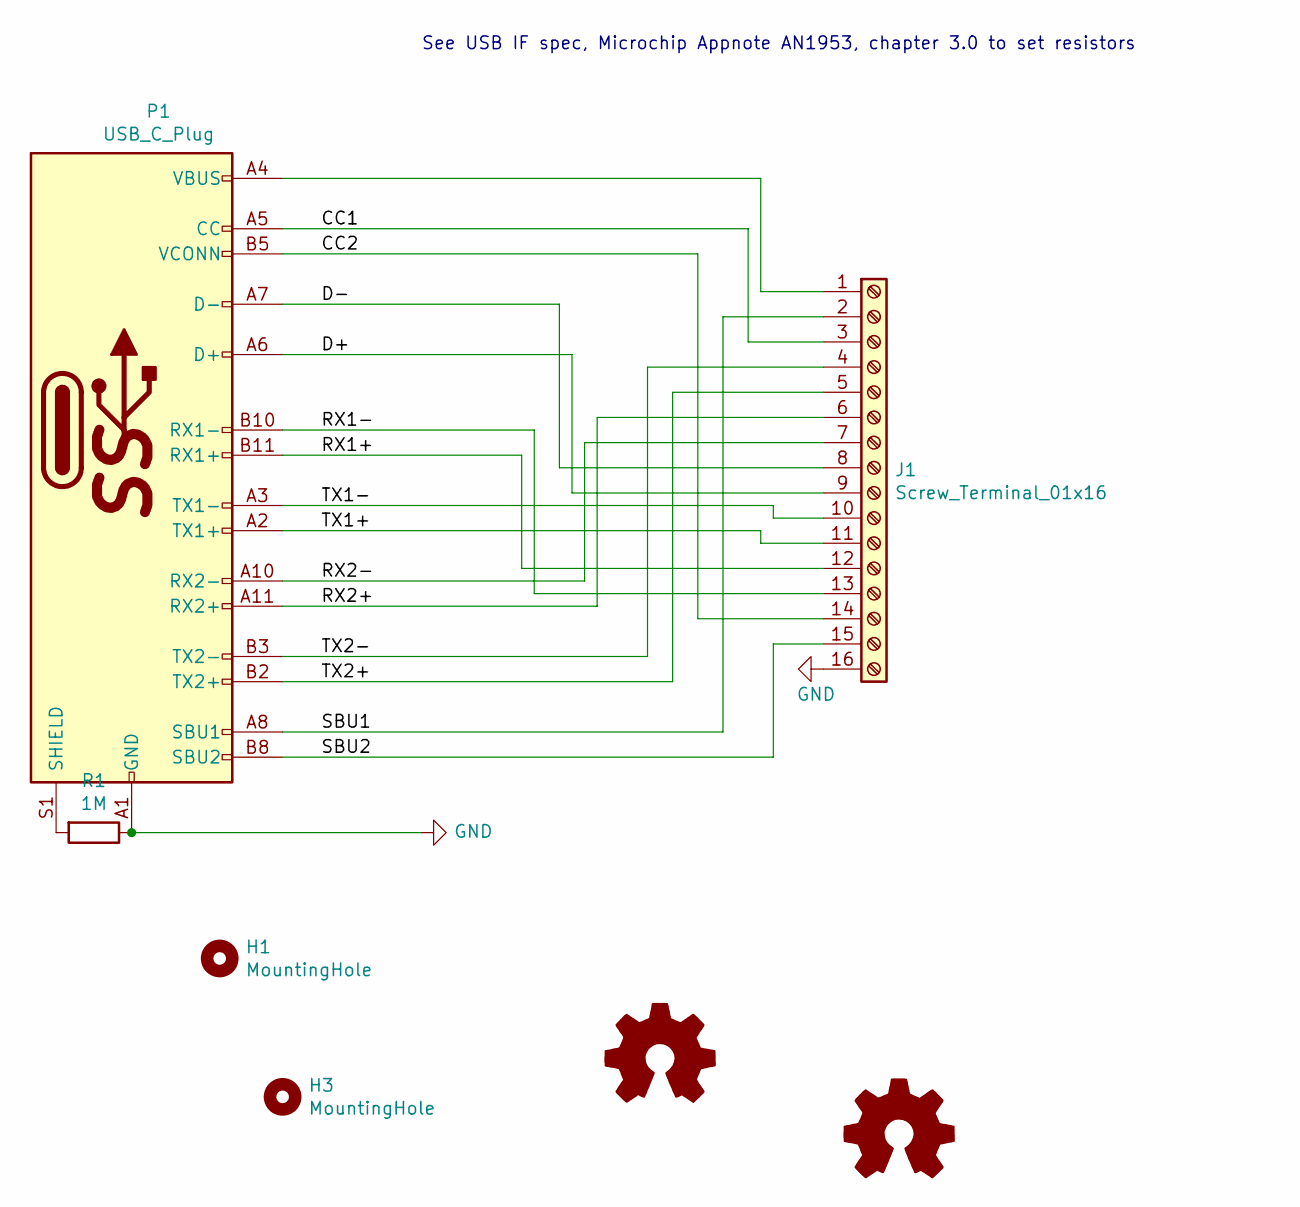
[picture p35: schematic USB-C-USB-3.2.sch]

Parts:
H1: MountingHole; MountingHole_3.2mm_M3_Pad_Via
H3: MountingHole; MountingHole_3.2mm_M3_Pad
J1: Screw_Terminal_01x16; PinHeader_1x16_P2.54mm_Vertical
L1: Logo_Open_Hardware_Small; OSHW-Logo_5.7x6mm_Copper
L2: Logo_Open_Hardware_Small; Bitraf_logo_3.0_x_7.5_mm
P1: USB_C_Plug; USB_C_Receptacle_Amphenol_12401548E4-2A
R1: 1M; R_0805_2012Metric_Pad1.15x1.40mm_HandSolder

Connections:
/CC1: J1.3, P1.A5 (CC)
/CC2: J1.14, P1.B5 (VCONN)
/D+: J1.9, P1.A6 (D+)
/D-: J1.8, P1.A7 (D-)
/RX1+: J1.12, P1.B11 (RX1+)
/RX1-: J1.13, P1.B10 (RX1-)
/RX2+: J1.6, P1.A11 (RX2+)
/RX2-: J1.7, P1.A10 (RX2-)
/SBU1: J1.2, P1.A8 (SBU1)
/SBU2: J1.15, P1.B8 (SBU2)
/TX1+: J1.11, P1.A2 (TX1+)
/TX1-: J1.10, P1.A3 (TX1-)
/TX2+: J1.5, P1.B2 (TX2+)
/TX2-: J1.4, P1.B3 (TX2-)
GND: J1.16, P1.A1 (GND), P1.A12 (GND), P1.B1 (GND), P1.B12 (GND), R1.1
unnamed: P1.S1 (SHIELD), R1.2
VBUS: J1.1, P1.A4 (VBUS), P1.A9 (VBUS), P1.B4 (VBUS), P1.B9 (VBUS)

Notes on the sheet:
See USB IF spec, Microchip Appnote AN1953, chapter 3.0 to set resistors

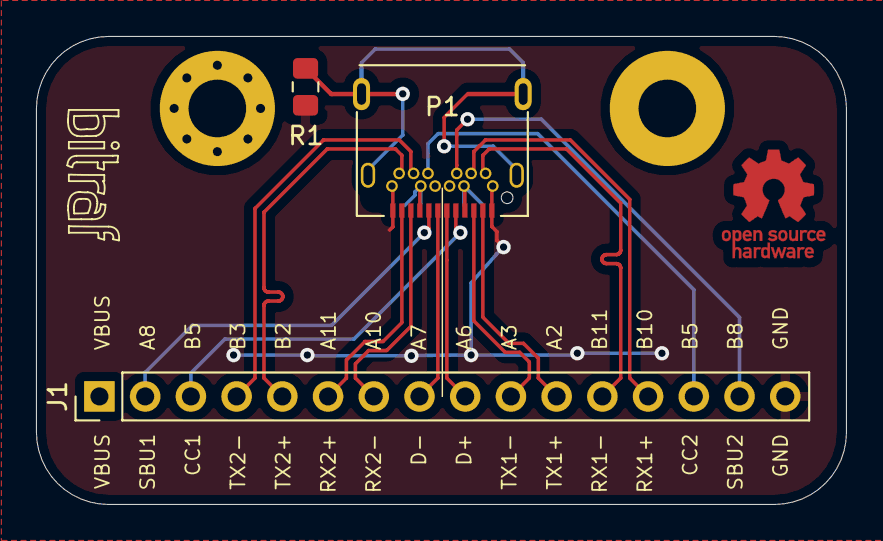
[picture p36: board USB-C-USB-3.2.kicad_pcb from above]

Board: 2 copper layers, 45.0 x 26.0 mm, 7 parts (0 on the bottom side), 17 nets.

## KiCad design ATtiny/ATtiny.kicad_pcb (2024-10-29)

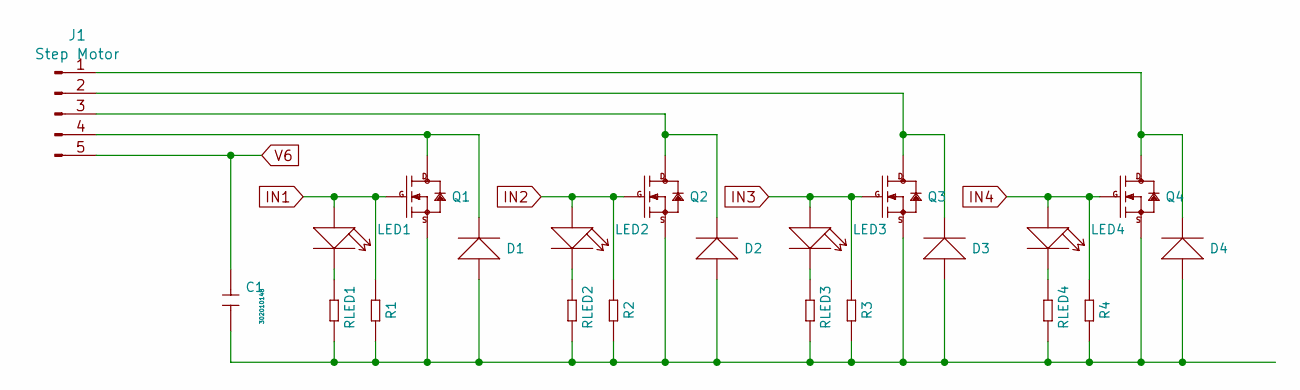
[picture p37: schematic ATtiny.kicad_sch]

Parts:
C1: CERAMIC-10UF-10V-10%-X7R_0805_; C_0805_2012Metric; MPN CC0805KKX7R8BB225; LCSC C126586
D1, D2, D3, D4: SMD-DIODE-SCHOTTKY-20V-1A_SOD-123_; D_0805_2012Metric; MPN B5819W; LCSC C84354
J1: Step Motor; JST_EH_B5B-EH-A_1x05_P2.50mm_Vertical
LED1, LED2, LED3, LED4: SMD-LED-CLEAR-RED_0805_; LED-0805; MPN 17-215SURC_S530-A2_TR8; LCSC C2764885
Q1, Q2, Q3, Q4: SMD-MOSFET-N-CH-20V-2.1A-CJ2302_SOT-23_; SOT95P240X115-3N; MPN CJ2302; LCSC C91104
R1, R2, R3, R4: SMD-RES-4.7K-5%-1_8W_0805_; R_0815_2038Metric; MPN RC0805JR-074K7L; LCSC C473295
RLED1, RLED2, RLED3, RLED4: SMD-RES-220R-5%-1_8W_0805_; R_0805_2012Metric; MPN RC0805JR-07220RL; LCSC C365277

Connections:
IN1: LED1.1 (+), Q1.1 (G), R1.1
IN2: LED2.1 (+), Q2.1 (G), R2.1
IN3: LED3.1 (+), Q3.1 (G), R3.1
IN4: LED4.1 (+), Q4.1 (G), R4.1
unnamed: C1.2, D1.1 (+), D2.1 (+), D3.1 (+), D4.1 (+), Q1.2 (S), Q2.2 (S), Q3.2 (S), Q4.2 (S), R1.2, R2.2, R3.2, R4.2, RLED1.2, RLED2.2, RLED3.2, RLED4.2
unnamed: D1.2 (-), J1.4, Q1.3 (D)
unnamed: D2.2 (-), J1.3, Q2.3 (D)
unnamed: D3.2 (-), J1.2, Q3.3 (D)
unnamed: D4.2 (-), J1.1, Q4.3 (D)
unnamed: LED1.2 (-), RLED1.1
unnamed: LED2.2 (-), RLED2.1
unnamed: LED3.2 (-), RLED3.1
unnamed: LED4.2 (-), RLED4.1
V6: C1.1, J1.5

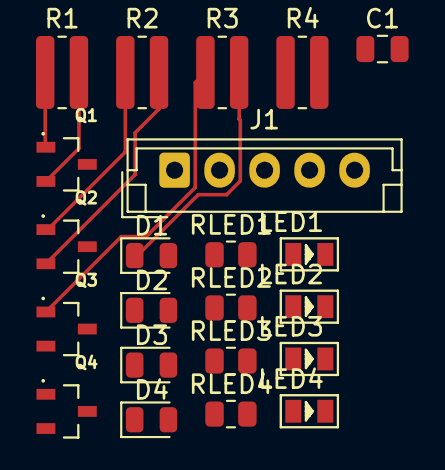
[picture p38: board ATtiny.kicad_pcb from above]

Board: 2 copper layers, 22 parts (0 on the bottom side), 14 nets.
